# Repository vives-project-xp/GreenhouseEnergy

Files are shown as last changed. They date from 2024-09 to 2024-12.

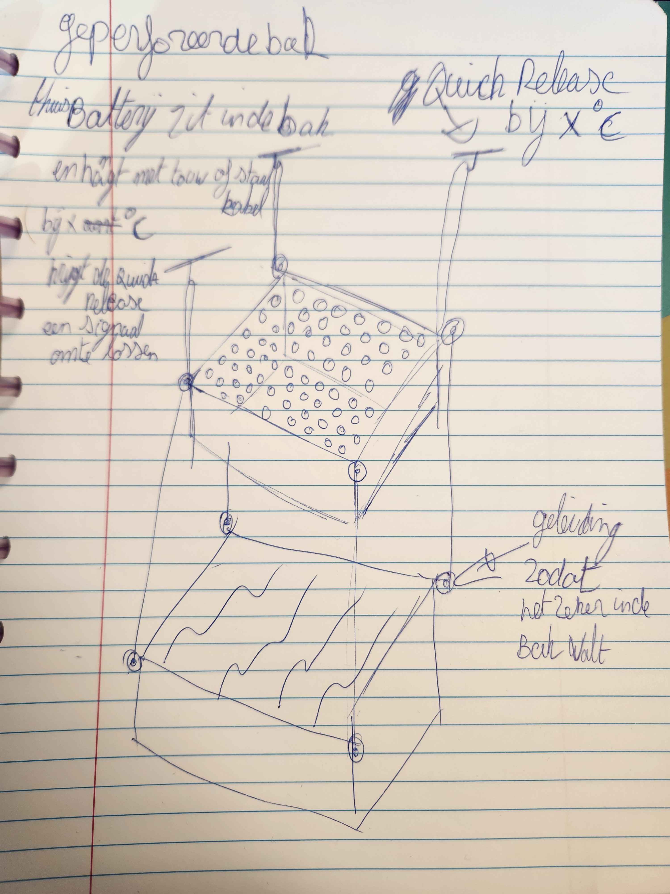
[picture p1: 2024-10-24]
Design/voorstellen_brandveiligheid/Concept_1.jpg

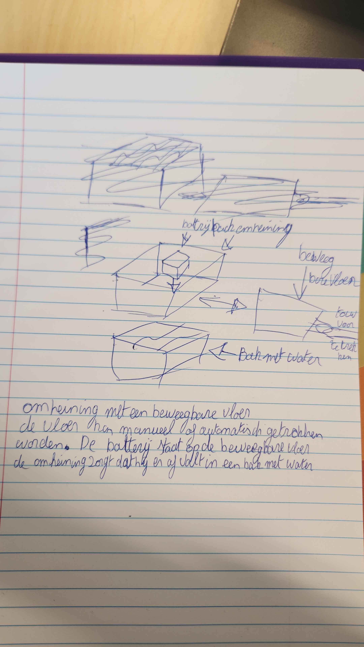
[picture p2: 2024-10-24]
Design/voorstellen_brandveiligheid/concept_2.jpg

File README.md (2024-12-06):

# Greenhouse Energy

## Index

- [The project](#the-project)
- [Wie zijn we](#wie-zijn-we)
- [Hardware](#hardware-en-functies)
- [Bill of Materials](#bill-of-materials)
- [Batterij](#de-batterij)

## The project
We kregen eerst de opdracht om elektriciteit te voorzien voor alle projecten die in de serre staan, maar na wat reflectie met de coaches kwamen we overeen dat we enkel een batterij oplaad systeem moesten ontwikkelen met monitoring voorzieningen. Nadien zullen de coaches een converter voorzien om de door ons opgewekte stroom naar 240V AC om te zetten en in het 2de semester komt er waarschijnlijk een opvolgend project die dan alles vervolledigd.

## Wie zijn we
- Seraphin Sampers (Scrum master, Researcher, IoT designer)
- Olivier Westerman (Communications, Administratie, Planning)
- Joshua Meuleman (Allround, Hardware specialist)

## Architectuur:
MPPT charger (1)

## Hardware en Functies
- BMS: Gezondheid van de batterij beschermen en sensordata leveren via UART.
- MPPT Charge controller: Opladen van de batterij aan het juiste voltage met de input van de zonnepanelen.
- Batterijen 13-Serieel NRC8650PF ,INR18650E en NRC8650B met 3.7V samen 48V, in een modulair systeem om meer parallel te kunnen plaatsen.
- Zekeringen tussen de MPPT, Batterij, Zonnepanelen (toekomstige uitbreiding) en Inverter (toekomstige uitbreiding).

## Bill of Materials
| Naam | Hoeveelheid | Prijs/eenheid | EAN nummer |
|---|---|---|---|
| Samsung INR18650-35E | min 13, max 260 | €2.99 | 9009316342928 |
| Nikkelstrip | 1m | €2.95 | 7417940525969 |
| JK Smart BMS | 1 | €64.20 | 7417940530888 |
| MPPT Charger | 1 | €88.53 | 8719076043027 |
| Zwarte Kabel 10mm² | 2m | €2.38 | 1524488 - 62 |
| Rode Kabel 10mm² | 2m | €2.64 | 602648 - 62 |
| Zwarte Kabel 16mm² | 2m | €3.64 | 602660 - 62 |
| Rode Kabel 16mm² | 2m | €3.64 | 602650 - 62 |
| Zekering 48v 20a | 1 | €0.86 | 2298-APT-20A-ND |
| Zekering 48v 30a | 1 | €0.86 | 2298-APT-30A-ND |
| Jumper kabel | 10 | €0.02 | Generisch |
| Logic Level Shifter | 1 | €3.12 | BOB12009 |
| ESP32-C3-DevkitM-1 | 1 | €6.00 | 1965-ESP32-C3-DEVKITM-1-ND |
| Mini Micro JST 2,0 mm 4-poliger stekker | 1 | €0.4 | Generisch |
| PVC shrinkwrap | 300mm diameter, 3m lang | €16.99 | B0DMNPQVVZ |

# De Batterij:
## Afmetingen
max 40cm(lengte) - 30cm (breedte) - 10cm (hoogte)
## Specificaties:
| Batterij | Berekend | Gemeten |
|---|---|---|
| Voltage | min 39V , average 48V, max 54.2V | average 48.2V |
| Ontlaadstroom | max 20A |  nvt | 
| Oplaadstroom | max 20A |  nvt | 
| Capaciteit | 1.25 kWh | 1.12 kWh|

Batterij Schematic

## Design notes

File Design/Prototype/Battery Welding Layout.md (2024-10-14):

TOP

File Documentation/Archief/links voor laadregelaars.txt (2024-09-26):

links voor laadregelaars

https://www.acculaders.nl/solar/solar-laadregelaar/
https://www.conrad.be/nl/o/laadregelaars-0509051.html
https://be.farnell.com/en-BE/samlex/msk-10a/solar-charge-controller-12v-24v/dp/3778667

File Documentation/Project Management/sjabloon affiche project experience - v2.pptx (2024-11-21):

Greenhouse Energy

Microscopische energie

-Het maken van een home battery op 48V.
-Brandveilige opslag ontwerpen.
-Monitoring data weergeven.
We kregen de opdracht om een energiebron te maken die de apparaten in de serre kunnen gebruiken. De energie zal duurzaam opgewekt worden met zonnepanelen en windmolens. Onze opstelling bevat enkel de batterij en het beheer ervan samen met sensor data over de gezondheid en laadtoestand van de batterij, de zonnepanelen en windmolens moeten nog worden toegevoegd. We hebben een output voltage van 48V DC maar deze zal door een converter nog naar 230V AC worden omgezet om zo hetzelfde te leveren als het stroomnet zodat de projecten zich niet steeds moeten aanpassen. Hiernaast moesten we ook nog een veilige manier om de batterijen in op te slaan ontwerpen zodat een mogelijke brand snel kan geblust worden.

P

Professionele bachelor
Elektronica-ICT

- Software Engineering
- Hardware Engineering
- Network- & System administration
- Personal development

Instructies:
1. Pas de project titel aan en voeg een subtitel toe
2. Schrijf eronder een korte omschrijving van de probleemstelling, jullie uitwerking, de gebruikte componenten en welke leerstof jullie nodig hadden.
3. Betreft het een project in opdracht van een bedrijf, plaats dan hun logo in de linker boven hoek.
4. Vervang de 3 foto’s door mooie foto’s van jullie product/prototype.
5. Noteer jullie namen bij het team
6. Indien een leerlijn niet werd gebruikt in jullie project, vervang het vinkje dan door een leeg vierkantje. Indien een leerlijn wel werd gebruikt vermeld er onder uit welke vakken je leerstof hebt toegepast.
7. Vervang de QR code door eentje die verwijst naar jullie GitHub repository.

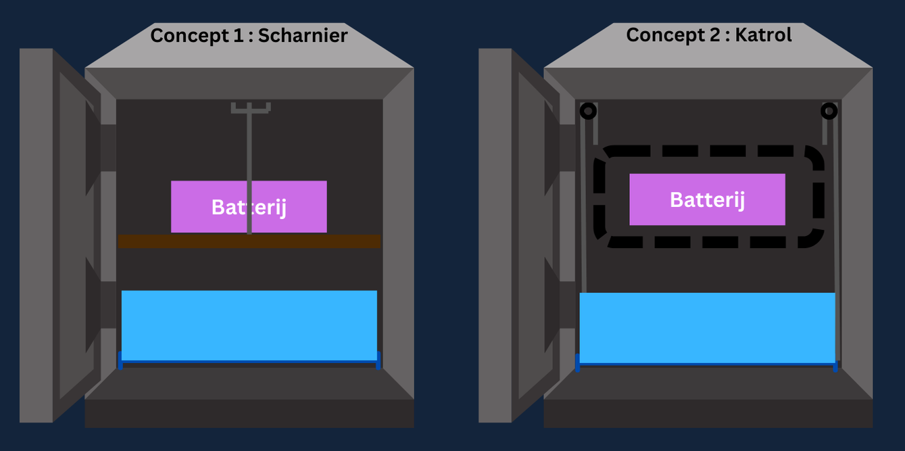
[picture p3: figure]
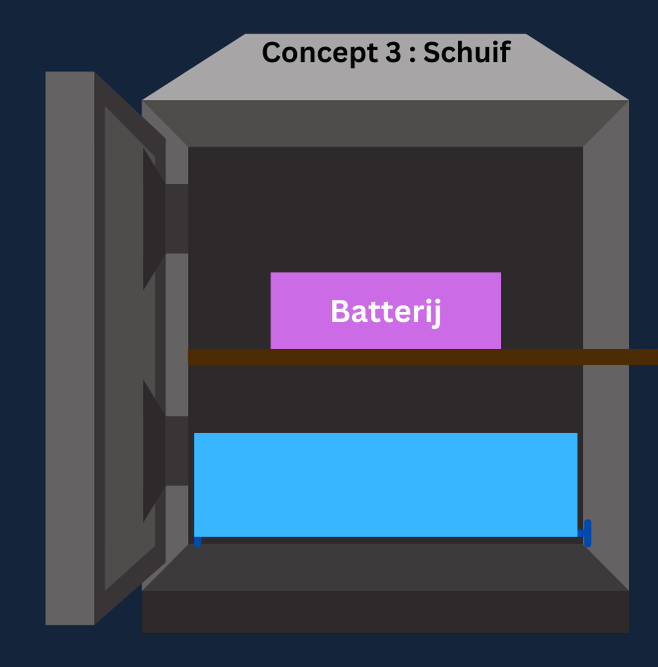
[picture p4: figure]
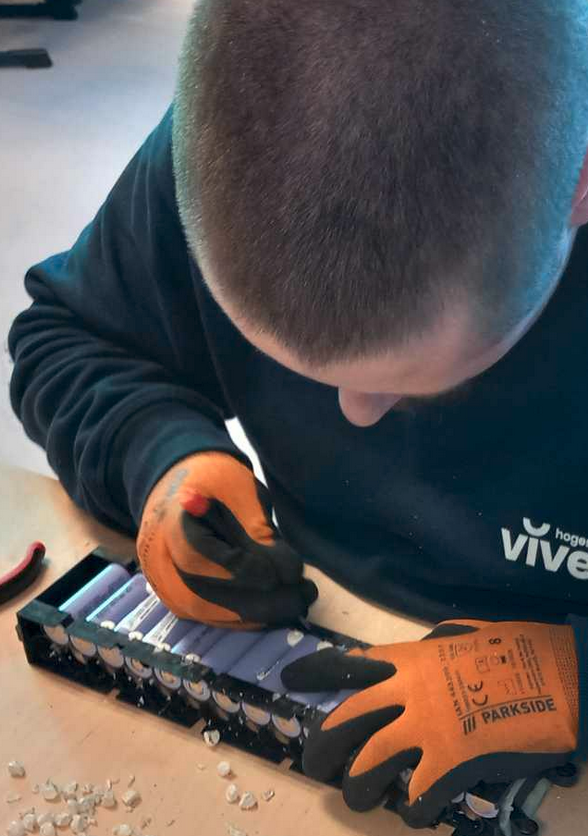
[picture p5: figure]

Team
- Olivier Westerman, Fase 2 Elektronica ICT
- Joshua Meuleman, Fase 1&2 Aangepast traject Elektronica ICT
- Seraphin Sampers, Fase 3 Elektronica ICT

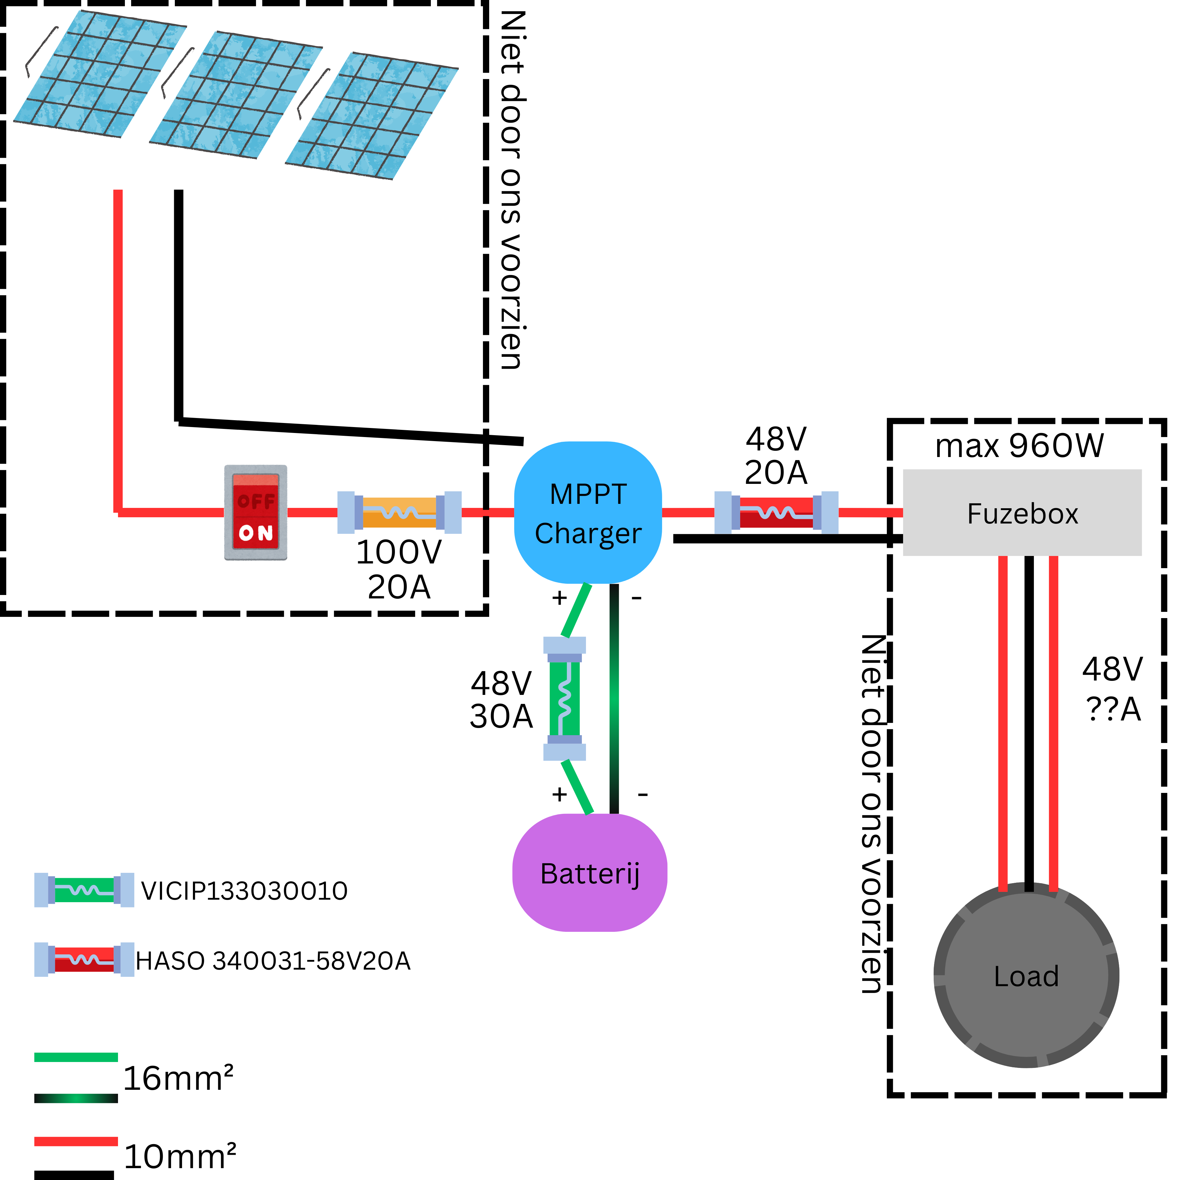
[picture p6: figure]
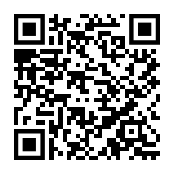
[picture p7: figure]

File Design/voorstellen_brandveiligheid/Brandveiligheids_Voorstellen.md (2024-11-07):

## Behuizing

### Kluis via 2dehands
In teams heeft Joshua heel wat kluizen beschikbaar op 2dehands.be gepost, variërend van prijzen van €100-300.  
Kluizen die speciaal zijn ontworpen om branden te weerstaan, kunnen temperaturen van 1000°C of hoger weerstaan, waarbij de binnentemperatuur onder de kritische 177°C blijft.

### Stalen doos
Staal begint te verzwakken vanaf 500°C en smelt tussen 1370°C en 1500°C. Let wel, de temperatuur in een stalen doos loopt sneller op dan in een brandwerende kluis.  
[McMaster Stalen doos van $271](https://www.mcmaster.com/products/steel-storage-boxes/chests-5/?s=steel-storage-boxes) is groot genoeg voor ons project.

### Professioneel
Een professioneel systeem biedt voordelen, zoals dat er geen extra bewateringssysteem nodig is omdat dit goed geregeld is.  
[Battery Safety Box - Medium II](https://www.batterysafetybox.com/sizes) lijkt een goede oplossing voor ons project. De prijs is niet zichtbaar zonder contact op te nemen, maar zal waarschijnlijk tussen de €1000-2000 liggen.

### Professioneel (met temperatuurmeter)
Dit product heeft een ingebouwde temperatuursensor, waardoor het de batterij automatisch in quarantaine kan zetten als er een probleem ontstaat.  
Het is specifiek ontworpen voor het opslaan van Lithium-ion batterijen.  
[EMTEZ Quarantine Safety Cabinets](https://www.emtez.be/nl-be/lithium-ion-quarantine-safety-cabinets)

Tenzij we voor de professionele opties gaan, zullen er enkele aanpassingen nodig zijn die ingrijpend of kostbaar kunnen zijn, namelijk:

1. Gaten boren in de kist om elektrische kabels te faciliteren.
2. Een onderwaterzet-systeem inbouwen (custom projectwerk).

---

## Onderwaterzet Systeem

Batterij (1)

De bovenkant van het systeem moet zijn waar de kabels binnenkomen, omdat anders het water eruit zal lopen.

### Concept 1: Scharnier
Een lade is bevestigd aan de kluis via een scharnier aan de achterzijde. Een touw of kabel verbindt de voorkant van de lade met een haak of oog aan de bovenkant van de kluis.  
Wanneer de batterij begint te branden, brandt het touw door, en valt de lade weg, waardoor de batterij in het water valt.

### Concept 2: Katrol
Een geperforeerde doos houdt de batterij zwevend boven een waterbak. De doos is verbonden met de waterbak via een katrollensysteem.  
Als de batterij begint te branden, brandt het touw door en valt de batterij in het water, waardoor deze in de geperforeerde doos terechtkomt.

### Concept 3: Schuif
Dit concept heeft geen ingebouwde quick release. Door de lade naar buiten te schuiven (uit de kluis), kan een persoon op een veilige afstand de lade eruit trekken, zodat de batterij in het water valt.

---

Dit zijn slechts mogelijke concepten die verder moeten worden uitgewerkt. Het effectief realiseren van deze concepten valt niet binnen de scope of het budget van het Greenhouse Energy-project.

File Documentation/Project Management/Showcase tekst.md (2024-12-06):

# Greenhouse Energy: Een duurzame stap naar zelfvoorzienende serre

Het Greenhouse Energy project heeft als doel om onze serre van een onafhankelijke elektriciteitsvoorziening te voorzien. Dit doen we door een batterijsysteem te koppelen aan een intelligente laadregelaar (MPPT). De status van deze batterij wordt realtime gemonitord en visualiseerd op ons eigen dashboard.

## Van off-grid droom naar praktijkoplossing

Aanvankelijk was het de ambitie om de serre volledig zelfvoorzienend te maken met behulp van zonnepanelen en/of windturbines. Echter, door budgettaire beperkingen en de beschikbaarheid van materialen hebben we een alternatieve oplossing bedacht: het simuleren van een thuisbatterij met een zelfgebouwde power pack.

## Een slimme en veilige batterijoplossing

Onze batterij is zorgvuldig ontworpen en gebouwd, inclusief een Battery Management System (BMS) dat de prestaties en veiligheid van de batterij optimaliseert. De zonnelader is aangesloten op de batterij en past de laadstroom dynamisch aan, afhankelijk van de energiebehoefte van de serre en de beschikbare zonne-energie.

Een ESP32 microcontroller fungeert als het 'brein' van het systeem. Deze verzamelt gegevens over de batterijstatus, de opbrengst van de zonnepanelen en het energieverbruik van de serre. Deze data wordt vervolgens verzonden naar ons Greenhouse Network-Monitoring dashboard, waar gebruikers in real-time de prestaties van het systeem kunnen volgen.

## Open-source en uitbreidbaar

Om de kennis en technologie te delen, hebben we alle relevante informatie, zoals handleidingen, elektrische schema's en uitbreidingsgidsen, openbaar gemaakt op GitHub: https://github.com/vives-project-xp/GreenhouseEnergy.

De huidige batterijoplossing vormt een solide basis voor toekomstige uitbreidingen. We hebben al een uitgebreide gids ontwikkeld die beschrijft hoe je de batterijcapaciteit kunt vergroten en het systeem kunt aanpassen om de oorspronkelijke off-grid doelstelling te bereiken. Bovendien zijn er voor uitgebreide brandveiligheidsmaatregelen concepten uitgewerkt om de veiligheid van het systeem te garanderen.

## De toekomst van Greenhouse Energy

Met Greenhouse Energy zetten we een belangrijke stap naar een duurzamere en zelfvoorzienende serre. Door het gebruik van innovatieve technologieën en een open-source aanpak willen we bijdragen aan de ontwikkeling van duurzame energieoplossingen voor zowel professionele als amateur tuinbouwers.

Omdat dit project niet de originele ambitie bereikt heeft, is er een uitbreidingsgids voorzien om ons project als springplank voor toekomstige projecten te ondersteunen.

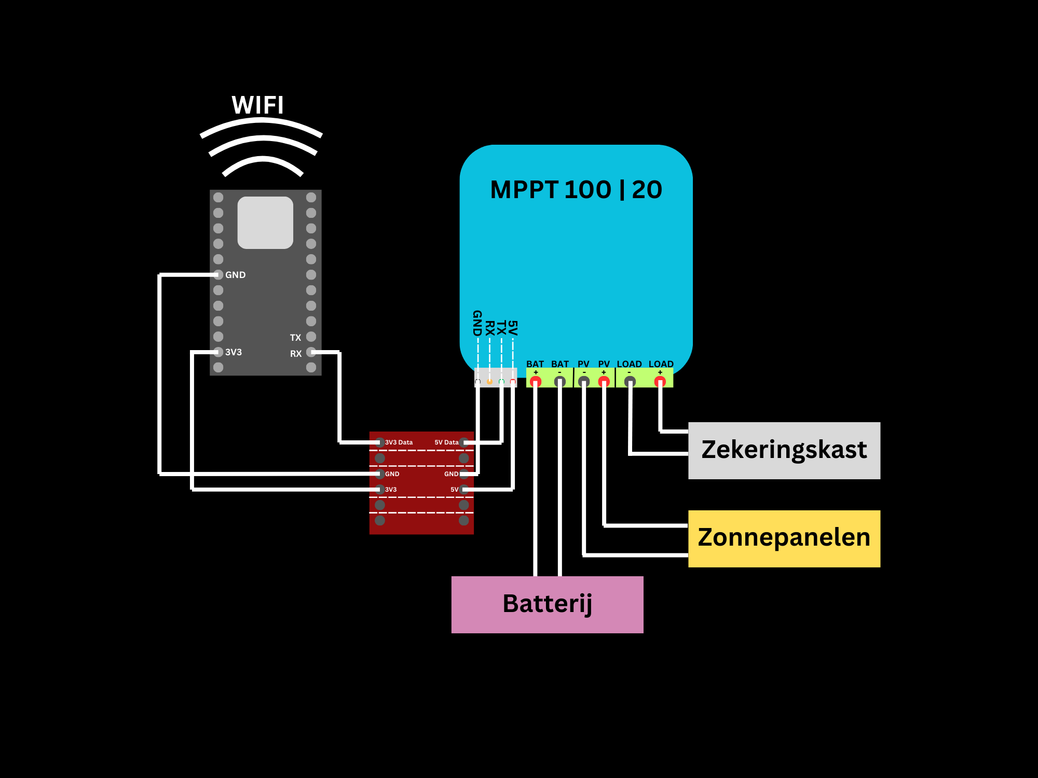
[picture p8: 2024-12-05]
Documentation/Schematics/Data Capture.png

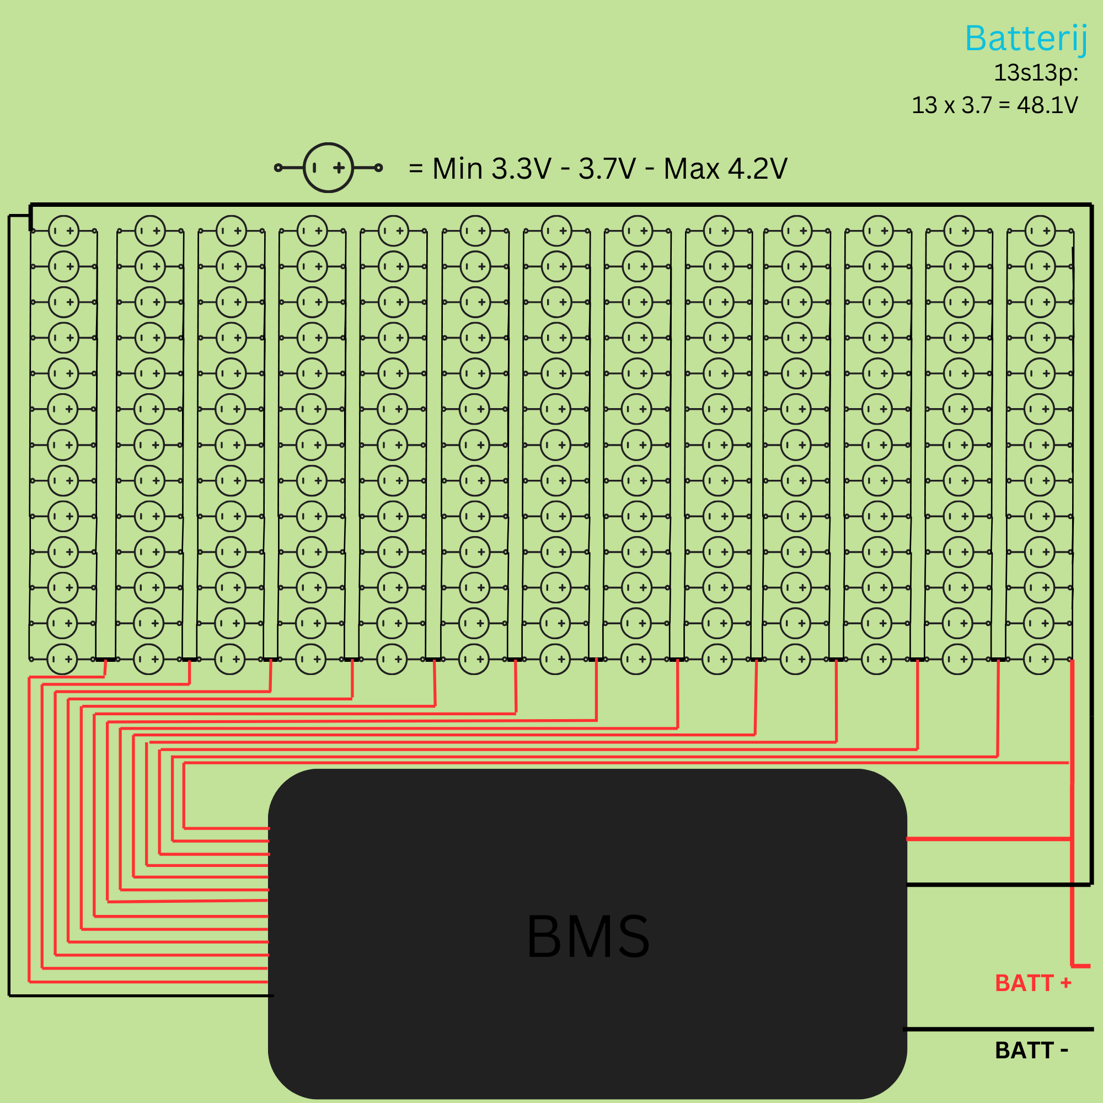
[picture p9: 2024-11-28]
Design/Batterij/Elektrisch schema batterij pack.png

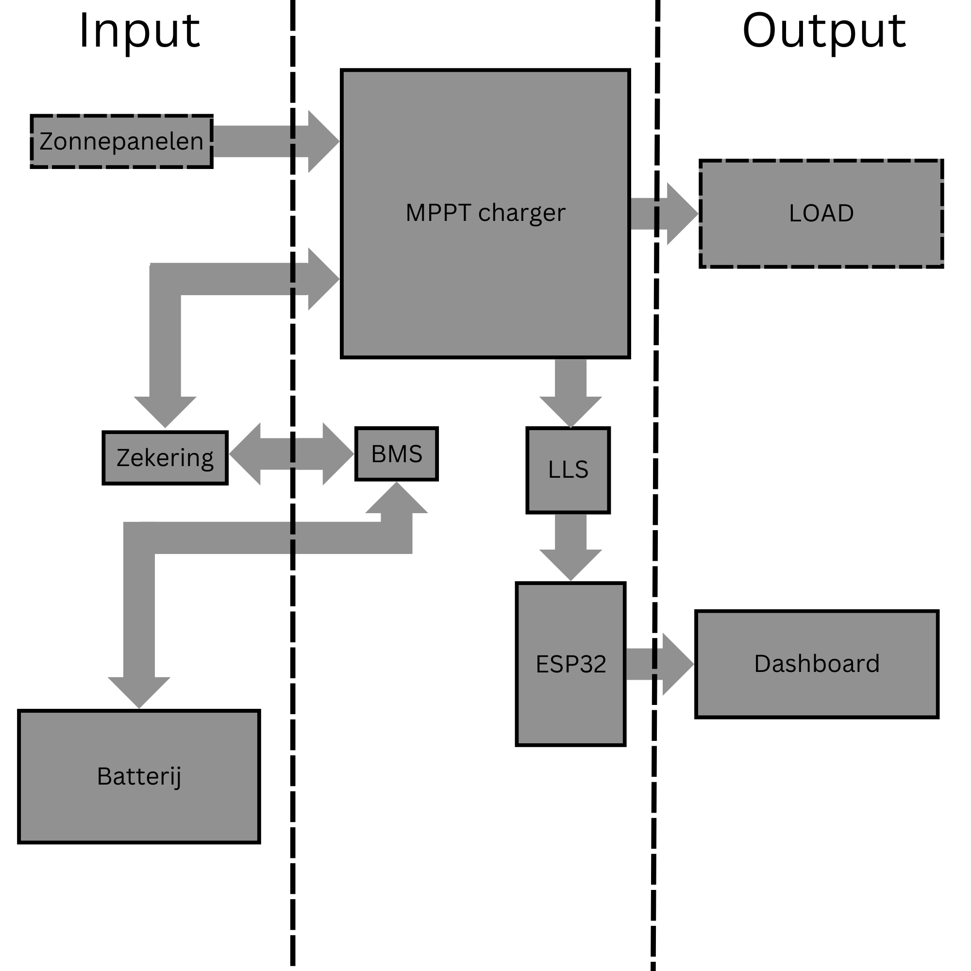
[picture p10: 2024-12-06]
Design/Architectuur.png

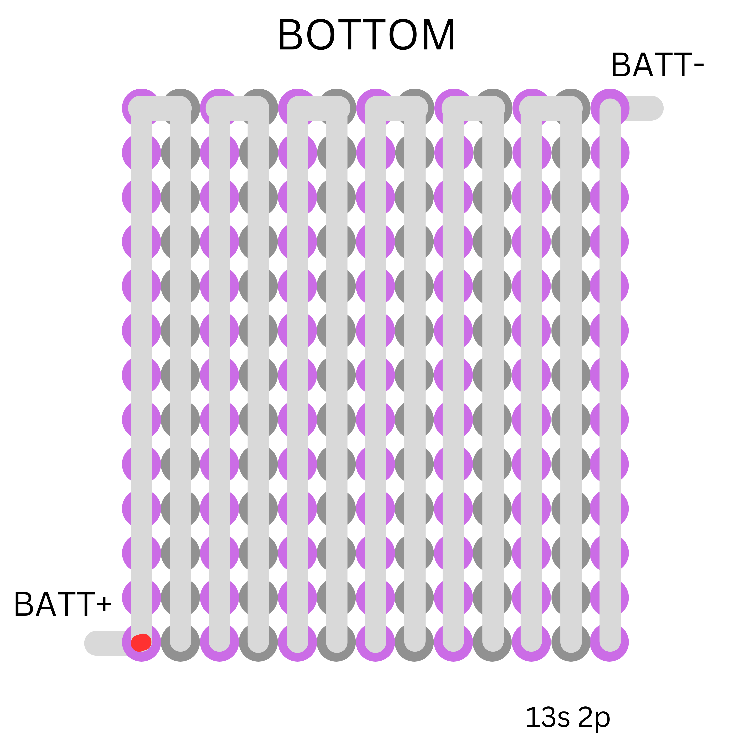
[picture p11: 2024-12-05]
Documentation/Schematics/Batterij BOTTOM view.png

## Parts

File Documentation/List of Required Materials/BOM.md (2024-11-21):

1. Brackets  V  
2. Nickel strips V
3. Puntlasser V
4. BMS V
5. MPPT charger V
6. Kabels V
7. Fuzeboxes (Max 30Ampere)
8. Brandkast

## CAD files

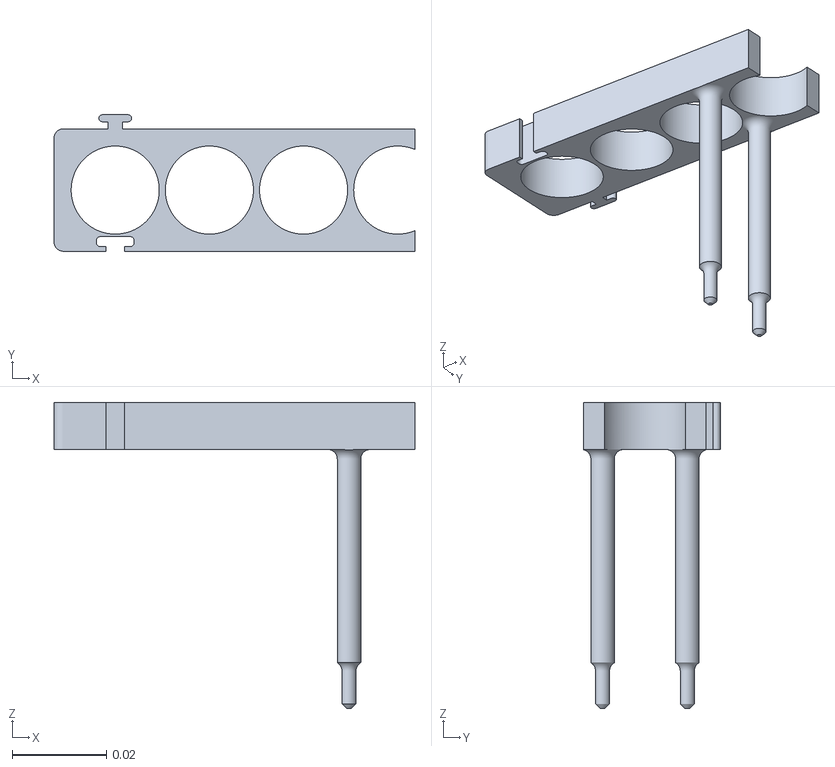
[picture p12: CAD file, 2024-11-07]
Design/Brackets 3D/Rapid Prototype Tests/Test_bottom_V1.2.stl
0.0767 x 0.029 x 0.065

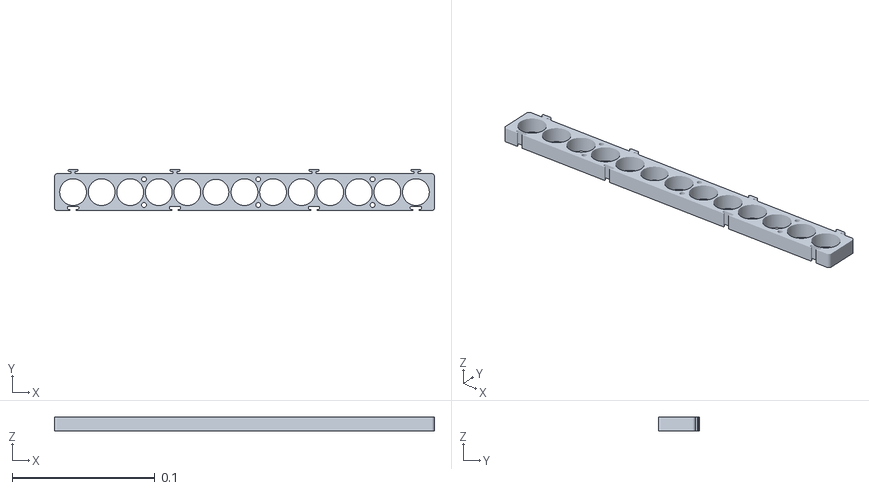
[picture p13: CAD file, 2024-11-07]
Design/Brackets 3D/Top_Volledig.stl
0.266 x 0.029 x 0.01

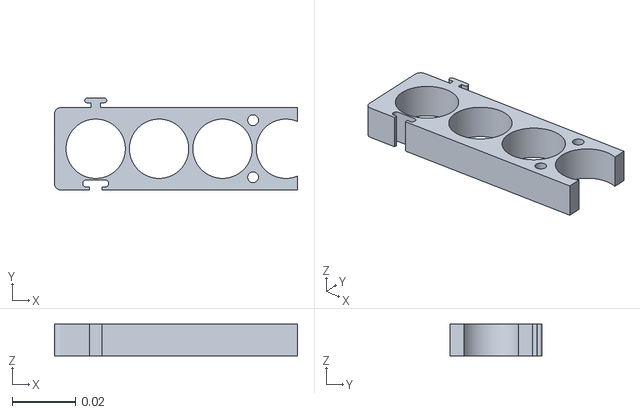
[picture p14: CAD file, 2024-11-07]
Design/Brackets 3D/Rapid Prototype Tests/Test_Top_V1.2.stl
0.0767 x 0.029 x 0.01

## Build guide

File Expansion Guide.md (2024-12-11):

# Uitbreiding Guide

**Let op**: Voordat je verder leest, blader eerst door deze GitHub-repository en lees vooral de README en de Installation Guide volledig door. Dit biedt essentiële basisinformatie voor de uitbreiding.

## Algemeen
Het ontwerpen van een uitbreiding kent veel mogelijke scenario's, waardoor het onmogelijk is om alle mogelijke situaties volledig te beschrijven. De energie-eis van jouw systeem zal grotendeels de bepalende factor zijn voor de opstelling.

Om deze reden starten we met een aantal voorbeeldscenario’s die een indicatie geven van de vereisten in verschillende situaties. Aan de hand van deze scenario's kun je een weloverwogen keuze maken voor jouw specifieke opstelling.

---

## Scenario’s

### Scenario 1: Gemiddeld dagelijks verbruik van 1 kWh
- **Inverter**: Victron Phoenix 48/1200 (VE.Direct)
- **Charger**: SmartSolar 100/30 MPPT
- **Batterij**:
  - 48V met een minimale capaciteit van 3 kWh.
  - **Opties**:
    - 2 parallelle batterijpacks, elk 13s15p.
    - 3 parallelle batterijpacks, elk 13s10p.
- **Zonnepanelen**:
  - Eén of twee panelen van 400 Wp is voldoende.
  - **Aanbevolen**: parallelle opstelling voor betere betrouwbaarheid bij slecht weer.
  - **Maximale configuratie**: 3 panelen in serie, 3 parallel (resulterend in een configuratie van 100/33 V en 30/11 A).
- **Zekeringen en schakelaars**: Geschikt voor 30A en 48V.
- **Schematische voorstelling**:



### Scenario 2: Gemiddeld dagelijks verbruik van 5 kWh
- **Inverter**: Victron MultiPlus-II 48/5000/70-50 230V
- **Charger**: Victron SmartSolar MPPT 250/100
- Geen load connectors; rechtstreeks aangesloten op de batterij.
- **Batterij**:
- 48V met een capaciteit van minstens 10 kWh.
- **Mogelijke configuratie**: 4 parallelle packs, elk 13s20p.
- **Zonnepanelen**:
- Minstens 6 panelen van 400 Wp in een combinatie van serie en parallel voor een optimale balans tussen voltage en stroom.
- **Zekeringen en schakelaars**: Geschikt voor hogere stroomsterktes, minimaal 100A.
- **Schematische voorstelling**:

victron 5kWh

### Scenario 3: Gemiddeld dagelijks verbruik van 10 kWh
- **Inverter**: Victron Quattro 48/10000/140-100/100
- **Charger**: Victron SmartSolar MPPT 250/100
- **Batterij**:
- 48V met een minimale capaciteit van 20 kWh.
- **Mogelijke configuratie**: 6 parallelle batterijpacks, elk 13s30p.
- **Zonnepanelen**:
- Twaalf panelen van 400 Wp.
- **Aanbevolen configuratie**: twee strings van zes panelen in serie.
- **Zekeringen en schakelaars**: Geschikt voor stroomsterktes tot 200A.
- **Schematische voorstelling**:



---

## Kosten schattingen

### Kosten Scenario 1 (1 kWh per dag)
- **Inverter**: Victron Phoenix 48/1200 (€350 - €450)
- **Charger**: SmartSolar 100/30 MPPT (€250 - €300)
- **Batterij**:
- Cell-prijs (bijvoorbeeld 18650-cellen): ± €2 per cel.
- 390 cellen = €780
- Inclusief BMS en behuizing: €200 - €300 extra.
- **Zonnepanelen**: 
- 1 of 2 panelen van 400 Wp (€150 - €200 per paneel = €150 - €400)
- **Montagemateriaal**: €50
- **Zekeringen en schakelaars**: €50 - €100
- **Totale kosten**: €1.400 - €2.100

### Kosten Scenario 2 (5 kWh per dag)
- **Inverter**: Victron MultiPlus-II 48/5000/70-50 (€1.200 - €1.500)
- **Charger**: Victron SmartSolar MPPT 250/100 (€700 - €1.000)
- **Batterij**:
- 13s20p = 260 cellen x 4 = 1.040 cellen = ± €2.080
- Inclusief BMS en behuizing: €400.
- **Zonnepanelen**: 
- 6 x 400 Wp (€150 - €200 per paneel = €900 - €1.200)
- **Montagemateriaal**: €200 - €300
- **Zekeringen en schakelaars**: €50
- **Totale kosten**: €5.380 - €6.500

### Kosten Scenario 3 (10 kWh per dag)
- **Inverter**: Victron Quattro 48/10000/140-100/100 (€2.500 - €3.000)
- **Charger**: Victron SmartSolar MPPT 250/100 (€700 - €1.000)
- **Batterij**:
- 13s30p = 390 cellen x 6 = 2.340 cellen = ± €4.680
- Inclusief BMS en behuizing: €600 - €800.
- **Zonnepanelen**: 
- 12 x 400 Wp (€150 - €200 per paneel = €1.800 - €2.400)
- **Montagemateriaal**: €300 - €500
- **Zekeringen en schakelaars**: €100 - €200
- **Totale kosten**: €9.980 - €11.900

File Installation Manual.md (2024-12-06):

# Greenhouse Battery: Installation Manual

## Inhoudstafel

1. [Benodigdheden](#1-benodigdheden)  
    1.1 [Materialen](#11-materialen)  
    1.2 [Gereedschap](#12-gereedschap)  
    1.3 [3D Prints](#13-3d-prints)  
2. [Batterij Pack](#2-batterij-pack)  
    2.1 [Testen van Batterijen](#21-testen-van-batterijen)  
    2.2 [Opladen van de Batterijen](#22-opladen-van-de-batterijen)  
    2.3 [Lekstroom Test](#23-lekstroom-test)  
    2.4 [3D Prints Voorbereiden](#24-3d-prints-voorbereiden)  
    2.5 [Cel Configuratie](#25-cel-configuratie)  
    2.6 [Puntlassen](#26-puntlassen)  
    2.7 [BMS Bevestigen](#27-bms-bevestigen)  
    2.8 [PVC Shrink Wrap](#28-pvc-shrink-wrap)  
3. [MPPT Charge Controller](#3-mppt-charge-controller)  
4. [Data Collectie](#4-data-collectie)  
    4.1 [Protocol](#41-protocol)  
    4.2 [Configureren van Arduino IDE](#42-configureren-van-arduino-ide)  
    4.3 [Code voor ESP32](#43-code-voor-esp32)  
5. [Achitectuur](#5-Architectuur)

---

## 1. Benodigdheden

### 1.1 Materialen

| Naam | Hoeveelheid | Prijs/eenheid | EAN nummer |
|---|---|---|---|
| Samsung INR18650-35E | min 13, max 260 | €2.99 | 9009316342928 |
| Nikkelstrip | 1m | €2.95 | 7417940525969 |
| JK Smart BMS | 1 | €64.20 | 7417940530888 |
| MPPT Charger | 1 | €88.53 | 8719076043027 |
| Zwarte Kabel 10mm² | 2m | €2.38 | 1524488 - 62 |
| Rode Kabel 10mm² | 2m | €2.64 | 602648 - 62 |
| Zwarte Kabel 16mm² | 2m | €3.64 | 602660 - 62 |
| Rode Kabel 16mm² | 2m | €3.64 | 602650 - 62 |
| Zekering 48v 20a | 1 | €0.86 | 2298-APT-20A-ND |
| Zekering 48v 30a | 1 | €0.86 | 2298-APT-30A-ND |
| Jumper kabel | 10 | €0.02 | Generisch |
| Logic Level Shifter | 1 | €3.12 | BOB12009 |
| ESP32-C3-DevkitM-1 | 1 | €6.00 | 1965-ESP32-C3-DEVKITM-1-ND |
| Mini Micro JST 2,0 mm 4-poliger stekker | 1 | €0.4 | Generisch |
| PVC shrinkwrap | 300mm diameter, 3m lang | €16.99 | B0DMNPQVVZ |

### 1.2 Gereedschap

- **Multimeter**: bv. Strex Digitale Multimeter - AC / DC  
- **Puntlasser**: bv. WANGCL 18650 battery spot welding  
- **Batterijlader**: bv. IMREN 18650 Batteries Battery Charger  
- **Striptang**  
- **Kniptang**  
- **Soldeerbout**: bv. YIHUA 929D-V Electric desoldering iron  
- **3D printer**: bv. Creality Ender 3  
- **Schuurpapier/Dremel**: bv. Dremel 3000 Multi Tool 130 W  
- **Heteluchtpistool**: bv. AIUNAOM Thermische heteluchtpistool  

### 1.3 3D prints

[STL Bottom](https://github.com/vives-project-xp/GreenhouseEnergy/blob/main/Design/Brackets%203D/Bottom_volledig.stl)
[STL Top](https://github.com/vives-project-xp/GreenhouseEnergy/blob/main/Design/Brackets%203D/Top_Volledig.stl)

## 2. Batterij Pack

### 2.1 Testen van Batterijen

Vooraleer je de INR18650-35E in je project kunt verwerken dien je ze grondig te testen op defecten, let hierbij op:

- **Corrosie op metalen oppervlakken**:  
  Deze kunnen indicatief zijn dat er interne corrosie aanwezig is, wat de batterij brandgevaarlijk maakt.
- **Beschadiging van het omhulsel**:  
  Op lange termijn is er een grotere kans op corrosie en verdere defecten.

Gebruik je digitale multimeter om de spanningen van iedere INR18650-35E te meten. De waarden zouden tussen de **3.3V en 4.2V** moeten liggen. Meet je minder dan 3.3V, dan is de cel ‘undercharged’. Er bestaat een kans om deze cel nog te redden door die met een kleine stroom (max 300mA) op te laden, onder toezicht.

### 2.2 Opladen van de Batterijen

Iedere INR18650-35E cel dient opgeladen te worden naar dezelfde (maximale spanning) vooraleer er kan gepuntlast worden.  
Gebruik hiervoor je batterijlader ingesteld op een stroom van max 1A.

### 2.3 Lekstroom Test

Laat de opgeladen batterijen 14-21 dagen onaangeroerd liggen en meet opnieuw de spanningen van iedere INR18650-35E cel.  
Is deze gezakt van **4.20V naar 4.00V** of lager, dan heeft deze cel een te grote lekstroom en gebruik je deze best niet voor je batterij pack.

### 2.4 3D prints voorbereiden

De voorziene STL hebben de exacte afmetingen voor je batterij, maar er is een grote kans dat er tijdens het printen afwijkingen zijn gecreëerd.  
Gebruik hiervoor wat schuurpapier, een vijl en/of dremel om hier en daar wat filament weg te schuren.  

**Aanpak:**  
- Gebruik een afgekeurde cel om iedere uitsparing te testen.  
- Markeer welke uitsparingen breder moeten gemaakt worden.  
- Schuur systematisch alle gemarkeerde gaten.  
- Besteed ook aandacht aan de aansluitpunten en schaaf bij als deze niet mooi op elkaar passen.

### 2.5 Cel configuratie

Batterij TOP view
Batterij BOTTOM view

Plaats alle cellen in hun 3D-print brackets zoals aangeduid in de blueprint.  
Deze opstelling komt overeen met een **13s13p configuratie** (*s = serieel, p = parallel*).

**Uitleg configuratie:**  
- **13 serieel** = 13 × 3.7V = **48.1V** (nominale gewenste spanning).  
- **Parallel:** Verbind beide positieve polen en beide negatieve polen van de cellen. Dit vergroot de batterijcapaciteit.  
- **Serieel:** Verbind de positieve pool van de eerste cel met de negatieve pool van de tweede. Dit verhoogt de spanning.

### 2.6 Puntlassen
Batterij TOP view
Batterij BOTTOM view

Gebruik de nikkelstrip en puntlasser om de verbindingen te maken volgens de blueprint:  
- Knip stukken van de nikkelstrip in de juiste lengte.  
- Leg de nikkelstrip op de pool van de cel en gebruik de puntlasser om de nikkel aan de cel te smelten.  

**Opmerkingen:**  
- Plaats extra lengte nikkelstrip (2 cm) op de **BATT+** en **BATT-** om later op te solderen.  
- Controleer met een multimeter dat iedere seriële celgroep (13 parallelle cellen) **4.2V** bijdraagt aan de totale spanning.  
- Totaal spanning over **BATT-** en **BATT+** moet **54.2V** zijn (13 × 4.2V).

### 2.7 BMS bevestigen
Batterij Schematic

- Plaats de JK Smart-BMS op de platte bovenkant van de batterijpack.  
- Soldeer rode kabeltjes aan iedere nikkelbrug tussen de celgroepen, zoals aangegeven in de blueprint.  
- Zorg voor nette verbindingen door onnodige lengte kabels af te knippen.  
- Soldeer de kabels alleen op de nikkelstrip, niet op de celpool, om beschadigingen te voorkomen.  

Bevestig de BMS met hotglue of adhesive tape op de batterijpack.  
Soldeer de **BATT+** en **BATT-** met 16mm² kabels aan de BMS voor verbinding met de volledige opstelling.

### 2.8 PVC shrink wrap

- Knip de rol PVC shrink wrap doormidden voor een groter vel.  
- Leg deze over de batterijpack en BMS totdat alles netjes bedekt is.  
- Gebruik een heteluchtpistool om de shrinkwrap te laten krimpen, zodat de batterijpack stevig ingepakt is.

## 3. MPPT Charge Controller

Macro Schematic

De MPPT charger heeft verbindingen voor:  
- **BATT** (batterijpack)  
- **PV** (zonnepanelen)  
- **LOAD** (verbruikers of inverter)

**Instructies:**  
- Strip de juiste kabels en verbind deze op de aangeduide plaatsen.  
- Plaats zekeringen zoals aangegeven in het schema.  
- Overweeg een differentieelschakelaar bij de LOAD, al is dit een duurdere optie.

## 4. Data collectie
Data Capture

### 4.1 Protocol: 
[Documentatie VE Direct protocol](https://github.com/vives-project-xp/GreenhouseEnergy/blob/main/Documentation/DataSheets/MPPT%20Charger/VE.Direct-Protocol-3.33.pdf) 

Onze gekozen MPPT charger gebruikt een propriëtair protocol genaamd **VE Direct** om data via UART uit te zenden.  
Bekijk de documentatie zorgvuldig voor meer details.

**Samenvatting:**  
- De charger stuurt iedere seconde data via UART.  
- Dit kan worden uitgelezen op een ESP32 en gedeeld via de ingebouwde Wifi- of Bluetooth-module van de ESP32.  
- Een **APA logic level shifter** is nodig om de 5V UART van de charger om te zetten naar 3V3 voor de ESP32.

### 4.2 Configureren van Arduino IDE
bron: https://samueladesola.medium.com/how-to-set-up-esp32-wroom-32-b2100060470c

- Stap 1: Arduino IDE
Gewoon downloaden op de site (https://www.arduino.cc/en/software)

- Stap 2: board selectie
 - Voeg "https://dl.espressif.com/dl/package_esp32_index.json" toe aan Preferences>Additionals boards manager URLs in arduino IDE.
 - Installeer "esp32" van Boards manager in arduino IDE, als je het niet direct vind moet je wat wachten tot de aanpassingen van vorige stap zijn gesynchroniseerd.
 - Selecteer "ESP32 Dev Module" als ontwikkel bord.
- Stap3: Drivers
**Linux**
Je kan kijken of de driver beschikbaar is op je systeem door dit uit te voeren:
`ls -al /lib/modules/"$(uname -r)"/kernel/drivers/usb/serial/cp210x.ko`
. Hierna kan je de driver activeren op de volgende manier:
`sudo modprobe cp210x`
. In sommige distros moet je jezelf ook nog toegang geven tot de esp op de usb via volgend commando:
`sudo usermod -aG dialout $(whoami)`
**Windows**
Je deze downloaden op https://www.silabs.com/developer-tools/usb-to-uart-bridge-vcp-drivers.

### 4.3 Code voor ESP32: 
**Code via Arduino IDE:**  
[Code]

# 5. Architectuur
MPPT charger (1)

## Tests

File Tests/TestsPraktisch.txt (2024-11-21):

Eerste test
Om erachter te komen hoeveel watt een batterij in het totaal heeft moeten we de Capaciteits test uitvoeren.
Voor een hele set te testen hebben we voor de INR 18650E batterij een ideale stroom gevonden: 3.5A. Omdat ze met 2 parralel staan per cel is de ideale ontlaad stroom voor de hele set 7A, omdat we geen weerstand konden vinden die 7A nemen we een max stroom van 1.8A (0.6A per weerstand).
We hebben dus een spanning van 48V en we willen 1.8A, dan hebben we 26 Ohm nodig, dan hebben we voor 3 parralle weerstanden 78Ohm nodig en zal er 0.6A per weerstand vloeien.

Opstelling:

+| -| +| -| +| -| +| -| +| -| +| -| +| -| +| -| +| -| +| -| +| -| +| -| +| -| +| -|  (13 batterijen in serie)
 |                                                                                      
 |----[W]--------+------------------------------+-------------------------------+      (W is de wattmeter)
                 |                              |                               |
                 [R1]                           [R2]                            [R3]   (3 weerstanden parallel)
                 |                              |                               |
                 +------------------------------+-------------------------------+

Als er een weerstand niet meer werkt dan doen we het met 1.2A weerstand: 40Ohm en 80Ohm per weerstand:

+| -| +| -| +| -| +| -| +| -| +| -| +| -| +| -| +| -| +| -| +| -| +| -| +| -|  (13 batterijen in serie)
 |                                                                                      
 |----[W]--------+-----------------------+                                      (W is de wattmeter)
                 |                       |
                 [R1]                    [R2]                                  (2 weerstanden parallel)
                 |                       |
                 +-----------------------+

We hebben een nieuw pak weerstanden gekregen met een max van 3W en 100R, volgens suggestie van mr. Vereeck was het beter om eerst met 1A te werken.
Hiervoor werken we met 6 Weerstanden parralel (16.66...R) en 3 in Serie (50R). Wattage per weerstand = (1/6)*16.66 = 2.77

Alternatief design: in plaats van 6 parralel, 3 in serie 10 parralel 5 in serie: De weerstand is hetzelfde maar het wattage per weerstand vermindert.
Totale weerstand: 10 * 5 = 50 Ohm
Stroom bij volledig opgeladen (54.3V) = 54.3/50 = 1.084A
Stroom bij ontladen = 39/50 = 0.78A

Met de watt meter kijken we periodiek hoeveel arbeid er wordt gelevert door de batterij en dan weten we hoeveel Wh er in de batterijen zit.
Af en toe schakelen we de wattmeter om naar een volt meter om te kijken of de batterijen ontladen zijn.
Voledig ontlaad spanning: 3*13 = 39V

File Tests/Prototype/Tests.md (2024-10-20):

(Je kan deze tests uitvoeren op verschillende temperatuuren om zo te kijken binnen welke temperatuurs ranges de batterijen goed werken.)

## Lek stroom test

Laadt de batterijen volledig op en laat ze liggen voor een week, als ze na een week nog steeds vol zijn dan heeft de batterij een kleine lekstroom.

## SoH test van de bms

Steek de batterijen in de bms, die dan de interne weerstand van de batterijen meet en zo de SoH bepaaldt.

## Capaciteits test (tijdsrovend, gebruik de test van de bms).

Laadt de batterijen volledig op en laat ze gecontrolleerd ontladen om zo erachter te komen hoeveel Ah of Wh er nog in zit.

## Totale test

Sluit het prototype aan op de BMS en bekijk de totale SoC, als dit in persentages wordt uitgedrukt dan moet je berekenen hoeveel Ah er in de batterijen zit (SoC/100 * totale Capaciteit Batterij * aantal batterijen), na het gecontrolleerd leeglopen moet er nog overschieten van wat je had - wat je verbruikt had.

## Oplaadt test

Probeer batterijen op te laden via de BMS, ze zouden niet meer dan 100% mogen worden en allemaal opgeladen moeten zijn als de BMS aangeeft dat de SoC 100% is.

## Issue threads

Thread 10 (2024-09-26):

Research BMS

OlivierWesterman, 2024-09-26:
Doe wat opzoekwerk over BMS'en voor het geval dat we een andere batterij oplossing nodig hebben dan de beloofde thuisbatterij.

joshuameuleman, 2024-10-03:
mogelijks hulplijn voor een BMS te maken https://www.youtube.com/watch?v=MR3aCU_enNE

Closed 2024-10-10.

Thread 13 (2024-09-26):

Design een testopstelling van Zonnepaneel

OlivierWesterman, 2024-09-26:
Om  al een eerste beeld te krijgen van wat we mogen verwachten van gemiddelde energie opbrengst moeten we het zonnepaneel eens testen. Denk na over hoe we dit doen en schrijf dit plan uit.

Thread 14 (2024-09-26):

Maak een architectuur document.

OlivierWesterman, 2024-09-26:
Schets in abstracte vorm de vebindingen tussen de apparaten die zullen gebruikt worden tijdens het project en hoe ze met elkaar zullen interacten. Maak hiervan een schema en wet die in Documentatie.

Closed 2024-10-10.

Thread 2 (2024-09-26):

Componenten selecteren

SampersS, 2024-09-26:
Met gebruik van de lijst van #9 en  de verkregen materialen van Vives, maak een beslissing over welke componenten dat we willen gebruiken.

joshuameuleman, 2024-10-10:
48v stepdown naar 12v 25 A

https://www.amazon.com.be/-/nl/waterdichte-spanningsomvormer-gelijkstroomuitgang-voedingstransformator-elektronische/dp/B09J4WRNZ1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

joshuameuleman, 2024-10-10:
48v stepdown naar 5v 8A

https://www.amazon.com.be/-/nl/waterdichte-spanningsomvormer-gelijkstroomuitgang-voedingstransformator-elektronische/dp/B09J4WRNZ1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

Closed 2024-11-04.

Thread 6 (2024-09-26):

Project Canvas Invullen

OlivierWesterman, 2024-09-26:
Samen met docent overlopen van de doelen, middelen, milestones, etc. om het project canvas in te vullen.

OlivierWesterman, 2024-09-26:
Project canvas op Github gevonden onder Documentatie.

Closed 2024-09-26.

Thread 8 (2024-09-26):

Excelsheet van Gevraagde Voltages

OlivierWesterman, 2024-09-26:
Maak een spreadsheet waar de studenten van andere projecten kunnen invullen hoeveel en welk voltage ze verwachten of wensen voor hen project. Deze issue is gelinkt aan #7.

OlivierWesterman, 2024-09-26:
Aangemaakt, kan terug gevonden worden onder Documentatie

Closed 2024-09-26.

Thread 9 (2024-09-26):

Lijst van mogelijke componenten opstellen

OlivierWesterman, 2024-09-26:
Als deel van de research, maak een lijst van opties met daarin mogelijkheden voor batterijen, laadregelaars, vermogensensoren, zonnepanelen. Deze lijst kan later uitegebreid worden indien nodig.

joshuameuleman, 2024-09-26:
vermogensensor uitleg : https://www.eaton.com/us/en-us/products/controls-drives-automation-sensors/sensors---limit-switches/power-sensor.html

vermogenmeter met display
https://www.benselectronics.nl/oled-volt-ampere-vermogens-meter-voor-paneel-inbou.html

SampersS, 2024-10-06:
componenten die we allesinds nodig hebben:
-micro controller: sensor inlezen en communicatie laad eenheid
-temperatuur sensor: per batterij, moet in design passen
-spanning sensor: per batterij

SampersS, 2024-10-06:
sinds we met redelijk wat cellen werken voorlopig gwn een stm32 gebruiken, wss gaan we dit dan ook nodig hebben in het uiteindelijke resultaat, reden: esp32 heeft wss niet genoeg gpio poorten
Ik neem volgende week wel mijn stm32 mee.

SampersS, 2024-10-06:
<a href='https://www.otronic.nl/nl/ds18b20-to92-temperatuur-sensor-dallas-clone.html'>https://www.otronic.nl/nl/ds18b20-to92-temperatuur-sensor-dallas-clone.html</a>

Dit als temperatuur sensor?

SampersS, 2024-10-06:
> vermogensensor uitleg : https://www.eaton.com/us/en-us/products/controls-drives-automation-sensors/sensors---limit-switches/power-sensor.html
>
> vermogenmeter met display https://www.benselectronics.nl/oled-volt-ampere-vermogens-meter-voor-paneel-inbou.html

met de nieuwe vereiste van 48V zal dit niet meer gaan (spannings metingen tot 33V)

Closed 2024-11-04.

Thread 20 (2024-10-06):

BMS design

SampersS, 2024-10-06:
Meer iets dat sensoren van de batterij uitleest en dan bepaald wat de soc is, ook verstuuren naar de stroombron dat hij moet kappen.
Dit moeten we dan ook toevoegen aan architectuur document.

joshuameuleman, 2024-10-10:
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

joshuameuleman, 2024-10-10:
https://www.amazon.com.be/-/nl/13S-48V-wifi-module-communicatiebeschermingskaart-Li-ion/dp/B0CY51CF45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

joshuameuleman, 2024-10-10:
https://www.dalybms.com/48v-lifepo4-bms-daly-k-series-smart-bms-3s-to-24s-40a-60a-100a-product/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

Closed 2024-10-10.

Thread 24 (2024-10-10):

Waar komen de fuses

SampersS, 2024-10-10:
Laten we dit als een thread gebruiken om te bespreken waar we de fuses zetten.

SampersS, 2024-10-10:
![Uploading Screenshot_2024-10-10_14-42-15.png…]()

SampersS, 2024-10-10:
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

SampersS, 2024-10-10:
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

SampersS, 2024-10-10:
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

SampersS, 2024-10-10:
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
Nieuwe fuse voor charger

SampersS, 2024-10-10:
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
aanpassing! geen converters meer nodig 🥳

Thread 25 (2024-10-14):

Verkrijgen veilige ruimte voor Dissassembly van Batterijen

OlivierWesterman, 2024-10-14:
Om veilig te kunnen werken met de batterijen zouden we best een labolokaal, een brandblusser gemaakt voor Li vuur, handschoenen en veiligheidsbril.
Labolokaal kan gereserveerd worden via vives
Brandblusser moet naar gevraagd worden bij de leerkrachten
Handschoenen en veiligheidsbril neem je mee van thuis

SampersS, 2024-10-15:
Email gestuurd naar de heer Calleeuw voor aanvraag labolokaal.

SampersS, 2024-10-20:
Sinds we geen labo kunnen verkrijgen en we al een bak met water hebben zal ik dit issue sluiten.

Closed 2024-10-20.

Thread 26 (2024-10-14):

Dissassemblen van batterijen pt.1

OlivierWesterman, 2024-10-14:
Nadat we een lokaal en materiaal hebben (#25), effectief uit elkaar halen van de batterijen.
Probeer hierbij zeer voorzichtig te werk te gaan, elke kortsluiting kan een volle brand starten en ons materiaal vernietigen.
Let ook op dat je jezelf niet bezeerd, bovenop het schuldgevoel dat ik er rond zou hebben zouden de batterijen kunnen corroden door je bloed en dat is een batterij voor de vuilbak dan.
Dit is deel 1, maak per 30min dat je er aan bezigbent een nieuwe issue die gewoon deel 2,deel3, ..... noemt.

Probeer ook minstens 1 foto te nemen van terwijl je bezig bent voor documentatie.

OlivierWesterman, 2024-10-24:
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

Closed 2024-10-24.

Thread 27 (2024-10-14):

Opstellen van Lay-out van de batterijen voor Prototype

OlivierWesterman, 2024-10-14:
Om een eerste idee te hebben en prototype zouden we al een 2 cellen van 13s parrallel schakelen en voltage meten.
Hiervoor moet een layout bedacht worden voor de batterijen en hoe die georienteerd moeten zijn om te kunnen gepuntlast worden.
Plaats deze layout (MS paint of ander programma) dan in Design.

OlivierWesterman, 2024-10-14:
Layout voor Welding kan gevonden worden in Design>Prototype>Batterij Layout voor spotwelding

Closed 2024-10-14.

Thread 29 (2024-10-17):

3D ontwerp van modulaire 13s batterij brackets

OlivierWesterman, 2024-10-17:
De brackets moeten 13 batterijen van 18650 model (18mm diameter) naast elkaar op 1 rij kunnen vasthouden.
Afstand tussen de batterijen is 2mm.
Het geheel moet passen op een 3d bed van 25x25 cm, liefst plat voor stevigheid maar kan ook diagonaal geprint worden.

OlivierWesterman, 2024-10-23:
Versie 1.0 die vorige week te klein bleek te zijn aanpassen naar een versie 1.1.
Eenmaal aangepast, nog een proef laten printen om te checken of de nieuwe versie wel groot genoeg is.

Risk: als de versie 1.1 te slecht is afgedrukt, vraag aan mnr.Leroy of je de settings mag specifieren van de 3D printer.

joshuameuleman, 2024-10-24:
versie 1.1 is doorgegeven voor te printen

wat is er veranderd?

Gaten voor batterij in te steken van 18mm -> 18.4mm
Gaten voor de afstand  tussen top en bottom 3mm -> 3.2mm
Modulaire systeem in het stuk 3.55->3.6   1.55->1.6
totale hoogte 3,1 maar met 2 delen 1.5 en 1.6 ->1.4 en 1.7

OlivierWesterman, 2024-11-04:
Duplicate, zie #59

Closed 2024-11-04.

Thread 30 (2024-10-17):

Puntlasser verkrijgen

OlivierWesterman, 2024-10-17:
Zoek rond in de familie of iemand een puntlassertje heeft, hoeft niet groot te zijn, is voor de nickelstrips aan de batterijen te lassen.

OlivierWesterman, 2024-10-19:
kleine puntlasser kunnen vinden via een vriend, ik breng deze mee en laat die in onze projectdoos achter op school.

Closed 2024-10-19.

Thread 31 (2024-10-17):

bekijk de prijzen voor 3d-printen

OlivierWesterman, 2024-10-17:
Vergelijk de prijs om 3 brackets van 13s (elk zou 10u duren om te laten printen) die we zelf designe te laten printen
vs
de prijs van 40 individuele brackets via temu

Closed 2024-10-17.

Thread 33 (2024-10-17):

Fuses en Kabel schema opstellen

OlivierWesterman, 2024-10-17:
Design een schema met alle fuses en max rating van stroom en spanning over de kabel.
Maak hierbij een legende voor de diameter van de kabel die hiervoor past en het model van de zekeringen.

OlivierWesterman, 2024-10-24:
toegevoegd aan elektrisch schema

Closed 2024-10-24.

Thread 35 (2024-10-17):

Ontwerp flooding system

SampersS, 2024-10-17:
Als er brand komt dan een manier om snel alles onder water te plaatsen, liefst met zoweinig elektronica mogelijk want door de brand kan het stoppen met functioneren.

Closed 2024-10-17.

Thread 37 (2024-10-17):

Handleiding maken

SampersS, 2024-10-17:
Dit hoort een document te zijn die aan een beginner zou beschrijven hoe je stap voor stap de batterij dient te maken zoals wij dat gedaan hebben.
Hierbij vermeldt je natuurlijk de nodige materialen, de instructies om die te assembleren, de procedures om te testen en algemene uitleg over de werking alsook waarschuwingen over gevaarlijke aspecten.

Closed 2024-12-06.

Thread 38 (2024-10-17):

Ontwerpen brandveiligheid systemen

SampersS, 2024-10-17:
We moeten systemen van verschillende prijs klasses voor brandveiligheid te berijken bedenken en dan voorleggen aan de leerkrachten en daarna kunnen zij kiezen.

OlivierWesterman, 2024-10-23:
Kijk hiervoor in de map Design voor een file met de naam Brandveiligheid_voorstellen.

Wat er concreet moet gebeuren:
Geef een drietal verschillende ideeen voor hoe we de batterij brandveilig zouden kunnen plaatsen.
Laat die varieren in prijs en kwaliteit, dus eentje goedkoop maar minder veilig, een middenslag en een duur maar betrouwbaar systeem.

Geef daar dus ook een geschatte kostprijs voor ieder concept en een ruw idee van welk materiaal je zou gebruiken bij elk.

Stuur gerust via teams als je nog een vraag hierover hebt.

joshuameuleman, 2024-10-24:
ik zal hier mogelijke sites zetten

https://www.emtez.be/nl-be/lithium-ion-quarantine-safety-cabinets : een aan te kopen kast die ontworpen is precies om lithium-ion batterijen op te bergen: heeft ook al een quarantaine bak bij 70°C zal de planken waar de batterij opstaat omkieperen

OlivierWesterman, 2024-11-04:
afgewerkt, zie Design>Brandveiligheid_voorstellen en #60

Closed 2024-11-04.

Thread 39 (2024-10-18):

tests ontwikkelen voor prototype en ook voor echte opstelling

SampersS, 2024-10-18:
We hebben tests nodig om uit te voeren op het prototype en de opstelling

SampersS, 2024-10-19:
Het testen van de batterijen werd gedaan door Olivier, maar we moeten nog kijken ofdat ze ook niet ontladen na een week om echt zeker te zijn dat ze nog goed zijn.

SampersS, 2024-10-19:
Er is nog een ander soort test die ook dient voor de gezondheid van de batterij te bepalen: voledig opladen en gecontrolleerd laten ontladen om te zien ofdat hun cappaciteit nog goed zit.

SampersS, 2024-10-19:
Maar omdat dit veel tijd in beslag neemt (zeker met de hoeveelheid aan batterijen die wij hebben) raad ik aan om gewoon de batterijen in de bms te steken als we die hebben en zo zal de bms de SoH van de batterijen bepalen aan de hand van de interne gemeten weerstand van de batterijen. (maar zetten we wel in de documentatie voor als men zeer zeker wilt zijn)

Closed 2024-11-04.

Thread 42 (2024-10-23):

Correcte fuses vinden online

OlivierWesterman, 2024-10-23:
We moeten nog fuses bestellen maar die zijn niet zo eenvoudig te vinden. fuse = zekering
Specifiek gaat het over:
1 fuse die op 48V 30Amp triggert
1 fuse die op 48V 20Amp triggert

Zoek een website die deze verkoopt en post de links in deze issue.

joshuameuleman, 2024-10-24:
Dit is een auto zekering die in uw zekeringsdoos zit van uw auto

deze zekering/fuse kan 30A op 48v aan.

voordeel: het heeft onze specs dat we nodig hebben

nadeel: nood aan een zekeringsdoos

https://www.digikey.be/nl/products/detail/optifuse/APT-30A/11581699

dit is van amazon kan 48v aan en je kan kopen in 20A en 30A
https://www.amazon.com/Hamolar-Circuit-Breaker-Resettable-Inverter/dp/B0B51X8FJ3?th=1

OlivierWesterman, 2024-11-04:
Toegevoegd aan bestellijst Excel.

Closed 2024-11-04.

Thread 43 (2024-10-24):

Concepten  bedenken voor Quarantaine bak

joshuameuleman, 2024-10-24:
Ik heb al 2 concepten bedacht en het staat onder design -> concepten

graag wil ik ze eerst bespreken met jullie voordat we de ideeën voorbrengen bij de docenten

heb je wonderbaarlijke ideeën maak een schets van uw concept en schrijft er uitleg bij :)
als we moeten bespreken en je weet niet meer wat je precies bedoelde met uw concept kan de uitleg uw helpen

Closed 2024-11-04.

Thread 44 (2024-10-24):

Dissassemblen van batterijen pt2

OlivierWesterman, 2024-10-24:
Nadat we een lokaal en materiaal hebben (https://github.com/vives-project-xp/GreenhouseEnergy/issues/25), effectief uit elkaar halen van de batterijen.
Probeer hierbij zeer voorzichtig te werk te gaan, elke kortsluiting kan een volle brand starten en ons materiaal vernietigen.
Let ook op dat je jezelf niet bezeerd, bovenop het schuldgevoel dat ik er rond zou hebben zouden de batterijen kunnen corroden door je bloed en dat is een batterij voor de vuilbak dan.
Dit is deel 2, maak per 30min dat je er aan bezigbent een nieuwe issue die gewoon deel 2,deel3, ..... noemt.

#
Probeer ook minstens 1 foto te nemen van terwijl je bezig bent voor documentatie.

Closed 2024-10-24.

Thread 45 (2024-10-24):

Dissassemblen van batterijen pt3

OlivierWesterman, 2024-10-24:
Nadat we een lokaal en materiaal hebben (https://github.com/vives-project-xp/GreenhouseEnergy/issues/25), effectief uit elkaar halen van de batterijen.
Probeer hierbij zeer voorzichtig te werk te gaan, elke kortsluiting kan een volle brand starten en ons materiaal vernietigen.
Let ook op dat je jezelf niet bezeerd, bovenop het schuldgevoel dat ik er rond zou hebben zouden de batterijen kunnen corroden door je bloed en dat is een batterij voor de vuilbak dan.
Dit is deel 3, maak per 30min dat je er aan bezigbent een nieuwe issue die gewoon deel 2,deel3, ..... noemt.

Probeer ook minstens 1 foto te nemen van terwijl je bezig bent voor documentatie.
#

Closed 2024-10-24.

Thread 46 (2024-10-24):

Dissassemblen van batterijen pt4

OlivierWesterman, 2024-10-24:
Nadat we een lokaal en materiaal hebben (https://github.com/vives-project-xp/GreenhouseEnergy/issues/25), effectief uit elkaar halen van de batterijen.
Probeer hierbij zeer voorzichtig te werk te gaan, elke kortsluiting kan een volle brand starten en ons materiaal vernietigen.
Let ook op dat je jezelf niet bezeerd, bovenop het schuldgevoel dat ik er rond zou hebben zouden de batterijen kunnen corroden door je bloed en dat is een batterij voor de vuilbak dan.
Dit is deel 4, maak per 30min dat je er aan bezigbent een nieuwe issue die gewoon deel 2,deel3, ..... noemt.

Probeer ook minstens 1 foto te nemen van terwijl je bezig bent voor documentatie.

Closed 2024-10-24.

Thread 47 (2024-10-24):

Dissassemblen van batterijen pt5

OlivierWesterman, 2024-10-24:
Nadat we een lokaal en materiaal hebben (https://github.com/vives-project-xp/GreenhouseEnergy/issues/25), effectief uit elkaar halen van de batterijen.
Probeer hierbij zeer voorzichtig te werk te gaan, elke kortsluiting kan een volle brand starten en ons materiaal vernietigen.
Let ook op dat je jezelf niet bezeerd, bovenop het schuldgevoel dat ik er rond zou hebben zouden de batterijen kunnen corroden door je bloed en dat is een batterij voor de vuilbak dan.
Dit is deel 5, maak per 30min dat je er aan bezigbent een nieuwe issue die gewoon deel 2,deel3, ..... noemt.

Probeer ook minstens 1 foto te nemen van terwijl je bezig bent voor documentatie.

Closed 2024-10-24.

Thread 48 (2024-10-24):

Dissassemblen van batterijen pt6

OlivierWesterman, 2024-10-24:
Nadat we een lokaal en materiaal hebben (https://github.com/vives-project-xp/GreenhouseEnergy/issues/25), effectief uit elkaar halen van de batterijen.
Probeer hierbij zeer voorzichtig te werk te gaan, elke kortsluiting kan een volle brand starten en ons materiaal vernietigen.
Let ook op dat je jezelf niet bezeerd, bovenop het schuldgevoel dat ik er rond zou hebben zouden de batterijen kunnen corroden door je bloed en dat is een batterij voor de vuilbak dan.
Dit is deel 6, maak per 30min dat je er aan bezigbent een nieuwe issue die gewoon deel 2,deel3, ..... noemt.

Probeer ook minstens 1 foto te nemen van terwijl je bezig bent voor documentatie.

Closed 2024-10-24.

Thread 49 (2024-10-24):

Dissassemblen van batterijen pt7

OlivierWesterman, 2024-10-24:
Nadat we een lokaal en materiaal hebben (https://github.com/vives-project-xp/GreenhouseEnergy/issues/25), effectief uit elkaar halen van de batterijen.
Probeer hierbij zeer voorzichtig te werk te gaan, elke kortsluiting kan een volle brand starten en ons materiaal vernietigen.
Let ook op dat je jezelf niet bezeerd, bovenop het schuldgevoel dat ik er rond zou hebben zouden de batterijen kunnen corroden door je bloed en dat is een batterij voor de vuilbak dan.
Dit is deel 1, maak per 30min dat je er aan bezigbent een nieuwe issue die gewoon deel 2,deel3, ..... noemt.

Probeer ook minstens 1 foto te nemen van terwijl je bezig bent voor documentatie.

Closed 2024-10-24.

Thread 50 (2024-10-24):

Dissassemblen van batterijen pt8

OlivierWesterman, 2024-10-24:
Nadat we een lokaal en materiaal hebben (https://github.com/vives-project-xp/GreenhouseEnergy/issues/25), effectief uit elkaar halen van de batterijen.
Probeer hierbij zeer voorzichtig te werk te gaan, elke kortsluiting kan een volle brand starten en ons materiaal vernietigen.
Let ook op dat je jezelf niet bezeerd, bovenop het schuldgevoel dat ik er rond zou hebben zouden de batterijen kunnen corroden door je bloed en dat is een batterij voor de vuilbak dan.
Dit is deel 1, maak per 30min dat je er aan bezigbent een nieuwe issue die gewoon deel 2,deel3, ..... noemt.

Probeer ook minstens 1 foto te nemen van terwijl je bezig bent voor documentatie.

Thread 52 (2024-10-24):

Dissassemblen van batterijen pt9

OlivierWesterman, 2024-10-24:
Nadat we een lokaal en materiaal hebben (https://github.com/vives-project-xp/GreenhouseEnergy/issues/25), effectief uit elkaar halen van de batterijen.
Probeer hierbij zeer voorzichtig te werk te gaan, elke kortsluiting kan een volle brand starten en ons materiaal vernietigen.
Let ook op dat je jezelf niet bezeerd, bovenop het schuldgevoel dat ik er rond zou hebben zouden de batterijen kunnen corroden door je bloed en dat is een batterij voor de vuilbak dan.
Dit is deel 1, maak per 30min dat je er aan bezigbent een nieuwe issue die gewoon deel 2,deel3, ..... noemt.

Probeer ook minstens 1 foto te nemen van terwijl je bezig bent voor documentatie.

Closed 2024-10-24.

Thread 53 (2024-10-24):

Dissassemblen van batterijen pt10

OlivierWesterman, 2024-10-24:
Nadat we een lokaal en materiaal hebben (https://github.com/vives-project-xp/GreenhouseEnergy/issues/25), effectief uit elkaar halen van de batterijen.
Probeer hierbij zeer voorzichtig te werk te gaan, elke kortsluiting kan een volle brand starten en ons materiaal vernietigen.
Let ook op dat je jezelf niet bezeerd, bovenop het schuldgevoel dat ik er rond zou hebben zouden de batterijen kunnen corroden door je bloed en dat is een batterij voor de vuilbak dan.
Dit is deel 1, maak per 30min dat je er aan bezigbent een nieuwe issue die gewoon deel 2,deel3, ..... noemt.

Probeer ook minstens 1 foto te nemen van terwijl je bezig bent voor documentatie.

Closed 2024-10-24.

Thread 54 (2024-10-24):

Dissassemblen van batterijen pt11

OlivierWesterman, 2024-10-24:
Nadat we een lokaal en materiaal hebben (https://github.com/vives-project-xp/GreenhouseEnergy/issues/25), effectief uit elkaar halen van de batterijen.
Probeer hierbij zeer voorzichtig te werk te gaan, elke kortsluiting kan een volle brand starten en ons materiaal vernietigen.
Let ook op dat je jezelf niet bezeerd, bovenop het schuldgevoel dat ik er rond zou hebben zouden de batterijen kunnen corroden door je bloed en dat is een batterij voor de vuilbak dan.
Dit is deel 1, maak per 30min dat je er aan bezigbent een nieuwe issue die gewoon deel 2,deel3, ..... noemt.

Probeer ook minstens 1 foto te nemen van terwijl je bezig bent voor documentatie.

Closed 2024-11-07.

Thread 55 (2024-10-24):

Testen 3D print Brackets versie 1.0

OlivierWesterman, 2024-10-24:
Dankzij mnr.Leroy hebben we een rapid protype kunnen testen.
Ondervindingen waren dat op meerdere plaatsen de print te weinig ruimte geeft voor de batterijen.
Een nieuwe issue wordt gemaakt om de print aan te passen.

Closed 2024-10-24.

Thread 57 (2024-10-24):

Testen 3D print Brackets versie 1.1

OlivierWesterman, 2024-10-24:
Nieuwe versie is geprint, nog steeds te nauw op verschilende plaatsen, aanpassingen moeten gemaakt worden. #56
De instellingen van de print zijn deze keer wel beter.

Een issue voor het designen van versie 1.2 wordt gemaakt. #57

Closed 2024-10-24.

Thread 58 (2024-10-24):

Design 3D print Brackets versie 1.2

OlivierWesterman, 2024-10-24:
na #58 moeten er kleine aanpassingen gedaan worden. Deze versie "zou" de laatste moeten zijn.

Hierna moet het getest worden opnieuw. Dit is een ander issue #59

Closed 2024-11-07.

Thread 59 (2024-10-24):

Testen 3D print Brackets versie 1.2

OlivierWesterman, 2024-10-24:
Na #58, opnieuw laten rapid printen met dezelfde instellingen en eens testen of de batterijen er nu wel in passen.

OlivierWesterman, 2024-11-07:
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
Succes, deze versie mag naar de printer.

Closed 2024-11-07.

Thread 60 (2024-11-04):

Bespreken van Brandveilige concepten met mnr Mees

OlivierWesterman, 2024-11-04:
We hebben een aantal concepten in Design>Branveiligheid die we kunnen voorleggen aan mnr.Mees en per extensie aan de veiligheidsdienst.

Belangerijk om erbij te vermelden is dat er geen budget en tijd meer is om deze volledig uit te werken tot afgewerkt product, we kunnen hooguit een prototype van een concept uitwerken. (en zelfs dat zal al nipt zijn dus niet opbrengen tenzij ze het echt vragen.)

OlivierWesterman, 2024-11-07:
zie #72

Closed 2024-11-07.

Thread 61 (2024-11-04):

Test schrijven voor prototype

OlivierWesterman, 2024-11-04:
Moet niet uitgebreid zijn, gewoon iets simpels waarmee we de spanning kunnen meten en het watuur ervan.
Zal waarschijnlijk een kleine opstelling vereisen waar we het prototype kunnen mee ontladen, opladen zonder BMS is een slecht idee.

OlivierWesterman, 2024-11-21:
Mogelijkse testen staan beschreven onder Tests>Prototype in Tests.md

Closed 2024-11-21.

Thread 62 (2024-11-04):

Contact opnemen met Technische dienst

OlivierWesterman, 2024-11-04:
Iemand van ons moet helpen met de opbouw van de serre.

Los daarvan moet er met hun besproken worden hoeveel ruimte moet voorzien zijn en waar in de serre om de stroom toe te laten komen.
Dit zal waarschijnlijk dezelfde hoek zijn waar onze batterij en charger eventueel zouden staan dus misschien iets groot genoeg voor een "kluis".

OlivierWesterman, 2024-11-21:
Opbouw van de serre is compleet, voeding zal komen van de fietsstalling.

Closed 2024-11-21.

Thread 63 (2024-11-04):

Alternatieve BMS-bron doorgeven

OlivierWesterman, 2024-11-04:
Blijkbaar is de website waar we de Dall-e BMS van zoudne bestellen niet goed genoeg voor de docenten dus moeten we een andere leverancier zoeken.

Als we die hebben voor ons model, moeten we de Excel-sheet updaten en mnr.Verstraete op de hoogte brengen zodat dit asap kan worden besteld.

OlivierWesterman, 2024-11-07:
Nieuwe BMS heeft geen smart devices on board omdat we ander uit budget gaan. Fietsunie is de nieuwe levernacier, excel met bestellingen is weer up to date.

Closed 2024-11-07.

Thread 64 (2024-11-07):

Doorsturen stl files naar printer

OlivierWesterman, 2024-11-07:
We zullen in het totaal 13 brackets nodig hebben, elk met hun top en bottom deel uiteraard.
Stuur deze door naar mnr. Leroy en voeg de bestelling ervan toe aan de excel.

joshuameuleman, 2024-11-21:
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

joshuameuleman, 2024-11-21:
Fotos toegevoegd

Closed 2024-11-21.

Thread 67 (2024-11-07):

Dissassemblen van batterijen pt11

OlivierWesterman, 2024-11-07:
Nadat we een lokaal en materiaal hebben (https://github.com/vives-project-xp/GreenhouseEnergy/issues/25), effectief uit elkaar halen van de batterijen.
Probeer hierbij zeer voorzichtig te werk te gaan, elke kortsluiting kan een volle brand starten en ons materiaal vernietigen.
Let ook op dat je jezelf niet bezeerd, bovenop het schuldgevoel dat ik er rond zou hebben zouden de batterijen kunnen corroden door je bloed en dat is een batterij voor de vuilbak dan.
Dit is deel 11, maak per 30min dat je er aan bezigbent een nieuwe issue die gewoon deel 2,deel3, ..... noemt.

Probeer ook minstens 1 foto te nemen van terwijl je bezig bent voor documentatie.

Closed 2024-11-07.

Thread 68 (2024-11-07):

Dissassemblen batterijen pt12

OlivierWesterman, 2024-11-07:
Nadat we een lokaal en materiaal hebben (https://github.com/vives-project-xp/GreenhouseEnergy/issues/25), effectief uit elkaar halen van de batterijen.
Probeer hierbij zeer voorzichtig te werk te gaan, elke kortsluiting kan een volle brand starten en ons materiaal vernietigen.
Let ook op dat je jezelf niet bezeerd, bovenop het schuldgevoel dat ik er rond zou hebben zouden de batterijen kunnen corroden door je bloed en dat is een batterij voor de vuilbak dan.
Dit is deel 1, maak per 30min dat je er aan bezigbent een nieuwe issue die gewoon deel 2,deel3, ..... noemt.

Probeer ook minstens 1 foto te nemen van terwijl je bezig bent voor documentatie.

Closed 2024-11-07.

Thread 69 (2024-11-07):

Dissassemblen van batterijen pt 13

OlivierWesterman, 2024-11-07:
Nadat we een lokaal en materiaal hebben (https://github.com/vives-project-xp/GreenhouseEnergy/issues/25), effectief uit elkaar halen van de batterijen.
Probeer hierbij zeer voorzichtig te werk te gaan, elke kortsluiting kan een volle brand starten en ons materiaal vernietigen.
Let ook op dat je jezelf niet bezeerd, bovenop het schuldgevoel dat ik er rond zou hebben zouden de batterijen kunnen corroden door je bloed en dat is een batterij voor de vuilbak dan.
Dit is deel 1, maak per 30min dat je er aan bezigbent een nieuwe issue die gewoon deel 2,deel3, ..... noemt.

Probeer ook minstens 1 foto te nemen van terwijl je bezig bent voor documentatie.

Closed 2024-11-07.

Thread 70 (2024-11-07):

Dissassemblen van batterijen pt14

OlivierWesterman, 2024-11-07:
Nadat we een lokaal en materiaal hebben (https://github.com/vives-project-xp/GreenhouseEnergy/issues/25), effectief uit elkaar halen van de batterijen.
Probeer hierbij zeer voorzichtig te werk te gaan, elke kortsluiting kan een volle brand starten en ons materiaal vernietigen.
Let ook op dat je jezelf niet bezeerd, bovenop het schuldgevoel dat ik er rond zou hebben zouden de batterijen kunnen corroden door je bloed en dat is een batterij voor de vuilbak dan.
Dit is deel 1, maak per 30min dat je er aan bezigbent een nieuwe issue die gewoon deel 2,deel3, ..... noemt.

Probeer ook minstens 1 foto te nemen van terwijl je bezig bent voor documentatie.

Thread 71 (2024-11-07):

Bespreken Test Prototype met mnr Vereecke

OlivierWesterman, 2024-11-07:
We weten te weinig over elektrische schema's om een goeie test te desigen , vraag aan mnr. Vereecke wat er moet gebeuren en hoe we best te werk gaan.

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

Closed 2024-11-07.

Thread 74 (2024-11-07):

Voorleggen van Prototype

OlivierWesterman, 2024-11-07:
Om onze project owner op de hoogte te houden van onze voortgang en ook de kans te geven voor bijsturing moet je het huidig prototype voorleggen en de werking bespreken.

Closed 2024-11-07.

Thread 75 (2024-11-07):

Administratie werk voor Github pt1

OlivierWesterman, 2024-11-07:
Als we niet hier de issue loggen gaan de docenten ervan uit dat er geen werk is geleverd dus deze issue en de volgende ervan dienen om aan te duiden dat deze issues correct maken en de upkeep van taken te verdelen een werk op zich is.

Closed 2024-11-07.

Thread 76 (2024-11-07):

Administratie werk voor Github pt 2

OlivierWesterman, 2024-11-07:
Als we niet hier de issue loggen gaan de docenten ervan uit dat er geen werk is geleverd dus deze issue en de volgende ervan dienen om aan te duiden dat deze issues correct maken en de upkeep van taken te verdelen een werk op zich is.

Closed 2024-11-07.

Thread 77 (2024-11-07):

Administratie werk voor Github pt 3

OlivierWesterman, 2024-11-07:
Als we niet hier de issue loggen gaan de docenten ervan uit dat er geen werk is geleverd dus deze issue en de volgende ervan dienen om aan te duiden dat deze issues correct maken en de upkeep van taken te verdelen een werk op zich is.

Closed 2024-11-07.

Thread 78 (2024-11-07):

Administratiewerk voor Github pt 4

OlivierWesterman, 2024-11-07:
Als we niet hier de issue loggen gaan de docenten ervan uit dat er geen werk is geleverd dus deze issue en de volgende ervan dienen om aan te duiden dat deze issues correct maken en de upkeep van taken te verdelen een werk op zich is.

Closed 2024-11-07.

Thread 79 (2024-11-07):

Administratiewerk voor Github pt 5

OlivierWesterman, 2024-11-07:
Als we niet hier de issue loggen gaan de docenten ervan uit dat er geen werk is geleverd dus deze issue en de volgende ervan dienen om aan te duiden dat deze issues correct maken en de upkeep van taken te verdelen een werk op zich is.

Closed 2024-11-07.

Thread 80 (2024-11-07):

Administratiewerk voor Github pt 6

OlivierWesterman, 2024-11-07:
Als we niet hier de issue loggen gaan de docenten ervan uit dat er geen werk is geleverd dus deze issue en de volgende ervan dienen om aan te duiden dat deze issues correct maken en de upkeep van taken te verdelen een werk op zich is.

Closed 2024-11-07.

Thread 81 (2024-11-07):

Informeren naar extra 3D printer

OlivierWesterman, 2024-11-07:
Indien de duur van de prints te lang is, zou het goed zijn om een extra printer te kunnen inschakelen.
Mnr Mees zou over een beschikken die hier eventueel zou kunnen voor dienen, contacteer hem hierover.

Closed 2024-11-07.

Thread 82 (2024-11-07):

Onderzoek data verkrijgen van Victron MPPT charger

OlivierWesterman, 2024-11-07:
Onze project owner heeft ons gevraagd om al vooruit te denken over hoe we eventueel data zouden kunnen verkrijgen van de MPPT charger, sinds die er duidelijk verzameld en via een propietary app via bluetooth doorstuurt.

Zoek online op of er al andere mensen hier iets op gevonden hebben en/of Victron dit ondersteund.
Zet hierbij alles dat je vindt in de folder Research.

OlivierWesterman, 2024-11-21:
VE direct protocol, met UART aansluiten te vinden op de charger zelf.
Via een microcontroller zoals een ESP32 kunnen we de data ontvangen en doorsturen via Wifi/Bluetooth.

SampersS, 2024-11-30:
Na het lezen van de documentatie over VE direct is vastgesteld dat we dit kunnen toepassen op een esp32 en dat het onderzoek dus voltooid is.

Closed 2024-11-30.

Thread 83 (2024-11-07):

Elektrisch schema van Batterij

OlivierWesterman, 2024-11-07:
Zowel mnr.Vereecke en mnr.Verstraete vroegen hiernaar.
Maak een elektrisch schema op waarbij je toont hoe de batterijen met elkaar in serie/parrellel staan en hoe dit geheel verbonden is met de BMS. Als je hiervoor de datasheet van de BMS kan vinden met het interne elektrische schema, des te beter, gebruik dan gerust dat erbij, anders is een abstractie van de BMS ook ok.

Let dus op, niet enkel de batterijen moeten juist afgebeeld staan, ook de kleine draadjes van de BMS die iedere cel monitort en de grotere draden van het BMS (zoals C-, B- en P-) met elk hun postitieve (C+, B+ en P+) connectiepunt moeten hier op aangeduid staan

OlivierWesterman, 2024-11-22:
Klaar, toegevoegd aan main README en Design>Batterij

Closed 2024-11-22.

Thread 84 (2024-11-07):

Testopstelling maken voor Prototype

OlivierWesterman, 2024-11-07:
Nu we een praktisch idee hebben van een capaciteitstest voor onze batterij (#65), moet deze opstelling gebouwd worden met behulp van de instelbare weerstanden die we gekregen hebben, de batterij zelf en de nodige bananekabels.

Eenmaal dit klaar is kun je verder naar issue #85, Capaciteitstest uitvoeren en monitoren.

OlivierWesterman, 2024-11-21:
Opstelling gemaakt, in plaats van instelbare weerstanden hebben we high-watt resistors kunnen gebruiken.
Het elektrisch schema van de opstelling staat onder Tests>Prototype>Capaciteitstest.

Closed 2024-11-21.

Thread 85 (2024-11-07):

Capaciteits Test voor Prototype uitvoeren

OlivierWesterman, 2024-11-07:
Bereken het theoretische Wattuur van het prototype en gebruik de opstelling van #84 om deze te vergelijken met de werkelijke waarde.

Sinds de weerstand een constante zal zijn zul je enkel de spanning over de batterij moeten monitoren terwijl de opstelling werkt tot de batterij 39V bereikt, vanaf dan moet je de kring onderbreken om undercharging te voorkomen.

Closed 2024-11-22.

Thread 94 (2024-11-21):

Data omzetten in grafiek van Capaciteitstest Prototype

OlivierWesterman, 2024-11-21:
Onder Tests>Prototype>Capaciteitstest staat een excelfile met de metingen tijdens de capaciteitstest.
Deze moet je een grafiek uit laten maken die de voltage en stroom plot in functie van de tijd.
Ten tweede moet er dan een berekening gedaan worden van hoeveel ampere-uur de batterijen meegingen vooraleer ze 39V bereikten.

OlivierWesterman, 2024-11-28:
De Ontladingsgrafiek werd gemaakt door Joshua, ik zal de berekeningen verder uitwerken en dan documenteren.

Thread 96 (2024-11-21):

Onderzoek naar ESP32 werking

OlivierWesterman, 2024-11-21:
We willen de UART signalen van de MPPT charger ontvangen op een ESP32 en dan doorsturen via Wifi, hoe doen we dat?
Plaats alle nuttige bevindingen onder Research

Closed 2024-12-01.

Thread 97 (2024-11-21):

Aansluiten van BMS op prototype

OlivierWesterman, 2024-11-21:
Om al eens te testen zou ons prototype best al eens een BMS krijgen.
Dit zal soldeerwerk vereisen, zowel de kleine kabeltjes per cel vrbinden, alsook grotere kabels aan het BMS plaatsen.

Closed 2024-11-28.

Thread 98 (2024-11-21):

Verbinden van Charger aan voeding

OlivierWesterman, 2024-11-21:
Om de charger al eens te testen kunnen we via kroko's een bannanakabel verbinden met de accukabels en die verbinden met de charger om de batterij te simuleren.
We kunnen deze kabels dan ook hergebruiken wanneer we de zonnepanelen willen simuleren.

Closed 2024-11-28.

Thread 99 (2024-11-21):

Spanningsdeler steken tussen MPPT charger en ESP32

OlivierWesterman, 2024-11-21:
MPPT charger geeft via UART signalen door die gescaled staan op 5V, onze ESP32 staat gescaled op 3V3.
Het meest eenvoudig is om een spanningsdeleropstelling te maken ertussen met de juiste weerstandjes en om van de 5V 3V3 te maken.

OlivierWesterman, 2024-11-28:
We hebben een Logic Level shifter kunnen verkrijgen in de plaats van de spanningsdeler, dit is beter voor de hogere frequentie signalen die we zullen doorsturen.

Closed 2024-11-28.

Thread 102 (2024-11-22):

Onderzoek doen naar hardware esp32

SampersS, 2024-11-22:
Dit omvatte het bekijken van wifi capabiliteit, uart en manier van stroomvoorziening, ook manieren om code te schrijven voor de esp32.

Het apparaat waarmee we werkten: esp32-wroom-32

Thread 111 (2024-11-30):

Uart doen werken op esp

SampersS, 2024-11-30:
Werk van donderdag
We hebben uart nodig om de mppt uit te lezen.
Dus eens kijken of we dat gewoon kunnen met de esp32.
Hiervoor gebruik ik de loopback test van uart
de chip ondersteunde het niet
de bootloader raakte corrupt dus we moesten opnieuw beginnen met een andere esp32
de chip ondersteunde het weer niet
veel tijd verloren met te kijken voor het werkende te krijgen.

Closed 2024-11-30.

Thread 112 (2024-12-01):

Loopback test uitvoeren

SampersS, 2024-12-01:
Na een beetje de documentatie te lezen vond ik dat ik pin 1 en 0 moest gebruiken voor uart1 om vanuit de pinnen te versturen en dan kan ik via uart0 de usb uitlezen, code voorbeeld voorlopig beschikbaar maar met deze uitleg makkelijk te reproduceren.

SampersS, 2024-12-01:
O ja ik zij eerder dat loopback niet ondersteund werd door de chip....
Dat was niet waar maar mijn code suckte gewoon (lol).

Closed 2024-12-01.

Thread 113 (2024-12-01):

Software testen en aanpassen

SampersS, 2024-12-01:
Wat moet er nog gebeuren:
 -Testen of de code wel werkt met de uart verbinding tot de mppt.
 -Kijken welke velden we krijgen van de mppt en beslissen welke we gaan doorsturen naar het dashboard.
 -Versturen via wifi in gang zetten en debuggen.
 -Kijken of de Checksum wel juist berekend wordt.

Closed 2024-12-07.

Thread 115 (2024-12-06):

half uur gaten groter maken

SampersS, 2024-12-06:
Voor een halfuur eb ik geholpen om de gaten in de 3d prints te vergroten dmv vijlen, dit is niets ivgl met Joshua die er heel de tijd mee bezig was, Olivier deed dit ook voor een lang stuk.

Closed 2024-12-06.

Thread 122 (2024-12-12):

arduino code debug

SampersS, 2024-12-12:
bug bug bug, dankzij aanzetten van debug data en de wijze raad van Nigel is homeassistent op de hoogte van de SoC

Closed 2024-12-12.

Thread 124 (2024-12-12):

Het harde werk van Joshua

SampersS, 2024-12-12:
Voor 2 voledige dagen alle prints uitvijlen omdat ze te nipt geprint waren.
Dit issue telt voor 28, straks worden er mischien 27 gemaakt door een bot.

Closed 2024-12-12.

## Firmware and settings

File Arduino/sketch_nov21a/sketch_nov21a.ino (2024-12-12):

#include <ArduinoJson.h>
#include <Arduino.h>
#include <math.h>
#include "connection.h"
#include "sensor.h"
#include "esp_task_wdt.h"
#include <HardwareSerial.h>

HardwareSerial UART_PIN(1);
HardwareSerial UART_USB(0);

#define WIFI_SSID "devbit"
#define WIFI_PASSWORD "Dr@@dloos!"
unsigned long lastTime = 0;
unsigned long timerDelay = 5000;
String json;
HaConnection connection;
HaSensor sensor;
esp_task_wdt_config_t twdt_config = {
    .timeout_ms = 60000,    //reset na 1 minuut als de timer niet wordt gereset
    .idle_core_mask = 0,    // Bitmask of all cores
    .trigger_panic = true,
};
void setup() {
  pinMode(2,OUTPUT);
  digitalWrite(2,1);//pin 2 gebruiken voor 3V3 output.
  UART_PIN.begin(19200, SERIAL_8N1, 0,1);
  //UART_PIN.setRxBufferSize(1024); //genoeg voor ontvangst van een voledige blok
  UART_USB.begin(115200);
  connection = HaConnection(WIFI_SSID, WIFI_PASSWORD, "10.10.2.20", 8123, 80, true);
  if (!connection.connected)
    return;
  sensor = HaSensor("SoC", SensorType::BATTERYLEVEL,0,100);
  esp_task_wdt_deinit();
  esp_task_wdt_init(&twdt_config);
  esp_task_wdt_add(NULL);
}

void loop() {
  BlokLees();
  delay(10000);
}
void BlokLees(){  //blokkerende functie tot het verzenden van een blok voltooid is.
  uint8_t field[9]; //maximuum groote van field
  uint8_t value[33]; //maximuum groote van value
  uint8_t index = 0;
  bool valueBezig = false;

  uint8_t byte = 0, prevbyte = 0;
  uint8_t cs = 0;
  unsigned long laatste = 0xffffffff; //Als de functie wordt opgeroepen zal er worden gewacht tot de de laatste
  
  //json initialisatie.
  JsonDocument doc;
  doc["card-name"] = "Energy";
  while(true){
    if(UART_PIN.available()){
      prevbyte = byte;
      byte = UART_PIN.read();
      cs += byte;
      if(valueBezig){
        if(prevbyte == 0x0D && byte == 0x0A){ //new line = volgende field
          valueBezig = false;
          value[index-1] = 0;
          index = 0;
          //code voor opslaan key-value paar.
          //nu gewoon nog in de terminal weergeven.
          //UART_USB.write((char *)&field[0]);
          //UART_USB.write(" - ");
          //UART_USB.write((char *)&value[0]);
          //UART_USB.write("\n\r");
          //voorbeeld voor json:
          if(strcmp((char *)&field[0],"V")==0){
            esp_task_wdt_reset();
            sensor.setValue(get_bat_persentage(atoi((char *)&value[0])));
          }
          //
        }else{
          if(index != 0 && index < 33){
            value[index-1] = prevbyte;
          }
          index++;
        }
      }else{
        if(index != 0 && index < 9){
          field[index-1] = prevbyte;
        }
        index++;
        if(byte == 0x09){ //horizontale tab = value nu
          valueBezig = true;
          field[index-1] = 0;
          index = 0;
        }
      }
      laatste = millis();
    }else{
      //apparaat verstuurt een blok van max 22 velden per seconde
      //boud rate = 19200
      //bits per char (8N1) = 10
      //byte snelheid = 1920Hz
      //dus als er 2ms geen byte binnen kwam dan is dat het einde van de blok.
      if(millis() - laatste <= 2){
        //check sum nagaan en opslaan van belangerijke fields.
        if(cs == 0){
          //Hier opslaan en verzenden, anders moeten de tijdelijke records weg.
          connection.sendData("Energy", {sensor});
        }
      }
    }
  }
}
int get_bat_persentage(int mv){
  /* Informatie komt uit test data.
  V: %
  52,71: 100
  51,45: 90
  50,34: 80
  49,29: 70
  48,35: 60
  47,66: 50
  47,09: 40
  46,5:  30
  45,77: 20
  42,72: 10
  40,9:  5
  39,1:  0
  */
  if(mv > 51450)
    return 100;
  if(mv > 50340)
    return 90;
  if(mv > 49290)
    return 80;
  if(mv > 48350)
    return 70;
  if(mv > 47660)
    return 60;
  if(mv > 47090)
    return 50;
  if(mv > 46500)
    return 40;
  if(mv > 45770)
    return 30;
  if(mv > 42720)
    return 20;
  if(mv > 40900)
    return 10;
  if(mv > 39100)
    return 5;
  return 0;
}

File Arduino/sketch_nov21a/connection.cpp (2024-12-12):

#include "connection.h"
#include <vector>
#include <ArduinoJson.h>

HaConnection::HaConnection() {};
HaConnection::HaConnection(String ssid, String password): HaConnection(ssid, password, "homeassistant.local", 8123, 80, false) {};
HaConnection::HaConnection(String ssid, String password, String HAIp, int HAPort): HaConnection(ssid, password, HAIp, HAPort, 80, false) {};
HaConnection::HaConnection(String ssid, String password, String HAIp, int HAPort, int port, bool output): ssid(ssid), password(password), server(WiFiServer(port)), HAIp(HAIp), HAPort(HAPort), port(port), output(output){this->setup();};

extern HardwareSerial UART_USB;

void HaConnection::StartMDNS()
{
    device_name = "greenhouse" + stringIP();
    if(output) UART_USB.print("starting MDNS");
    do{
        if (output) UART_USB.print(".");
        delay(250);
    }
    while (!MDNS.begin(device_name.c_str())) ;
    if (output)
    {
        UART_USB.print("\nMDNS gestart op ");
        UART_USB.print(device_name);
        UART_USB.print(".local\n");
    }
    MDNS.addService("_greenhouse", "_tcp", port);
};

void HaConnection::AttemptWifiConnection()
{
    WiFi.begin(ssid.c_str(), password.c_str());
    if (output) UART_USB.print("Verbinden met WiFi... ");
    do
    {
        if (output) UART_USB.println(".");
        delay(250);
    } while (WiFi.status() != WL_CONNECTED);
    UART_USB.println(WiFi.localIP());
};

void HaConnection::setup()
{
    this->AttemptWifiConnection();
    this->StartMDNS();
    this->connected = true;
    this->checkVersion();
};

void HaConnection::sendData(String card_name, const std::vector<HaSensor>& sensors) {
    String json = "{";

    String name = card_name.length() > 0 ? card_name : "Sensor";
    json += "\"card-name\":\"" + name + "\"," + "\"sensors\":[";
    for (HaSensor sensor : sensors) {
    
        json += sensor.toJson() + ",";
    }
    json = json.substring(0, json.length() - 1);
    json += "]}";
    if(output){
        UART_USB.println("Sending data: ");
        UART_USB.println(json);
        UART_USB.println();
    }

    sendHttpPost(json);
}

void HaConnection::sendHttpPost(String json) {
    if (WiFi.status() == WL_CONNECTED) {
        HTTPClient http;
        String url = "http://" + HAIp + ":" + HAPort + "/api/webhook/greenhouse" + stringIP();
        if(output) UART_USB.println(url);
        http.begin(url);
        http.addHeader("Content-Type", "application/json");
        int httpResponseCode = http.POST(json);
        if(output){
            if (httpResponseCode > 0) {
                String response = http.getString();
                UART_USB.println("Response: " + response);
            } else UART_USB.println("Error in sending POST: " + String(httpResponseCode));
        }
        
        http.end();
    } else {
        if(output) UART_USB.println("WiFi not connected");
        AttemptWifiConnection();
    }
}



String HaConnection::stringIP() {
    // Verkrijg het lokale IP-adres als een string
    String ip = WiFi.localIP().toString();

    ip.replace('.', '_');

    return "_" + ip;  // Voeg aan het begin een underscore toe
}

void HaConnection::checkVersion() {
    if (WiFi.status() == WL_CONNECTED) {
        HTTPClient http;
        String url = "https://api.github.com/repos/vives-project-xp/GreenhouseNetwork-Monitoring/releases/latest";
        http.begin(url);
        int httpResponseCode = http.GET();
        if (httpResponseCode > 0) {
            String response = http.getString();
            JsonDocument doc;
            deserializeJson(doc, response);
            String latestVersion = doc["tag_name"];
            if (latestVersion != version) {
                UART_USB.println("New version available: " + latestVersion + " -> https://github.com/vives-project-xp/GreenhouseNetwork-Monitoring/releases");
            }
        }
    }
}

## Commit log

2024-09-26 voltage excel
2024-10-10 BOM in progress.md
2024-10-10 fuse schema
2024-10-10 exelc backup
    [BestellingenEn3DPrints_2425-Sem1.xlsx]
2024-10-14 Create Battery Welding Layout.md
2024-10-14 Update Battery Welding Layout.md
2024-10-17 remove excel backup
    [BestellingenEn3DPrints_2425-Sem1.xlsx]
2024-11-07 3D prints added
    [Test_Top_V1.2.stl, Test_bottom_V1.2.stl, Top_Volledig.stl]
2024-11-21 Added ESP32 datasheets
2024-11-21 arduino code creatie
2024-11-22 Datasheets van BMS added
2024-11-23 arduino server connection (not tested)
2024-11-28 Capaciteitstest afgerond
    [Ontlaad data.xlsx]
2024-11-29 verbinden MPPT charger
2024-12-01 finalizatie esp32 code
2024-12-05 update arduino
2024-12-05 goede esp32 code
2024-12-05 repupload schematics
2024-12-12 esp32 fix
2024-12-12 esp32 toevoeg output pin
